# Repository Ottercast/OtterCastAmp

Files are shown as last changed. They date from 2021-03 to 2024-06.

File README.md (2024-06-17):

# OtterCastAmp

OtterCastAmp is an open-source Sonos Amp replacement, based on a Sochip S3 SoC and pulseaudio sink/source.

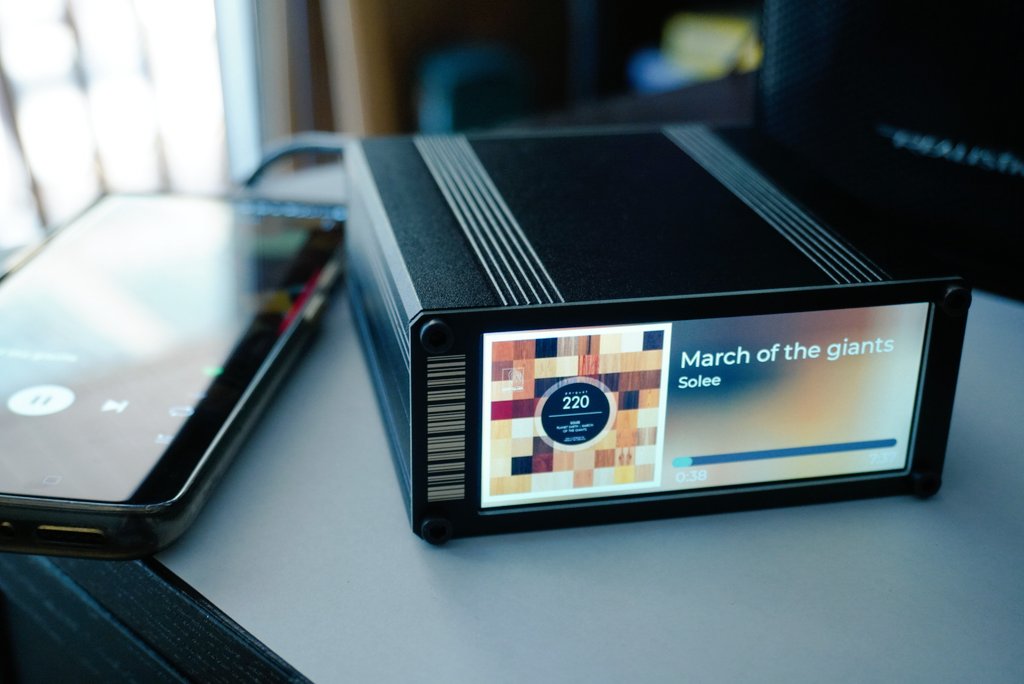
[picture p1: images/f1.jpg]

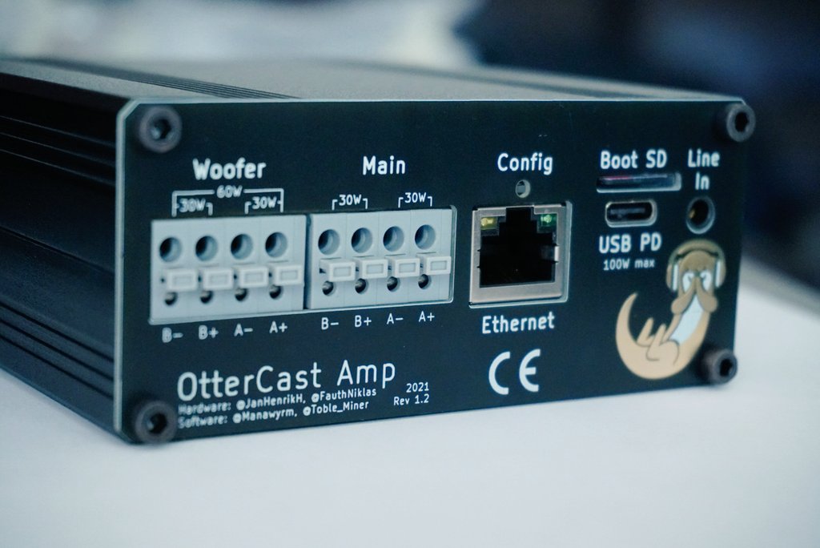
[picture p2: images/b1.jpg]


## How do I get one?

We are currently planning a small batch production run, stay tuned.
[editors notes: It is 2024 now and noone really expected how bad covid would affect the supply chain. While all parts are available again, we are only slowly getting interested in this project again]

You don't want to wait? You can of course run a small batch on your own! Please have a look into the [gerber folder](/gerber_v1.2), a batch size of just 5 (and up to 30) boards is supported by JLC.

## Installation & Configuration

After [downloading and flashing](https://cast.otter.jetzt/docs/firmware/#download-ready-made-images) the image, OtterCastAmp can either be configured via the `config.ini` file or via the web-interface.

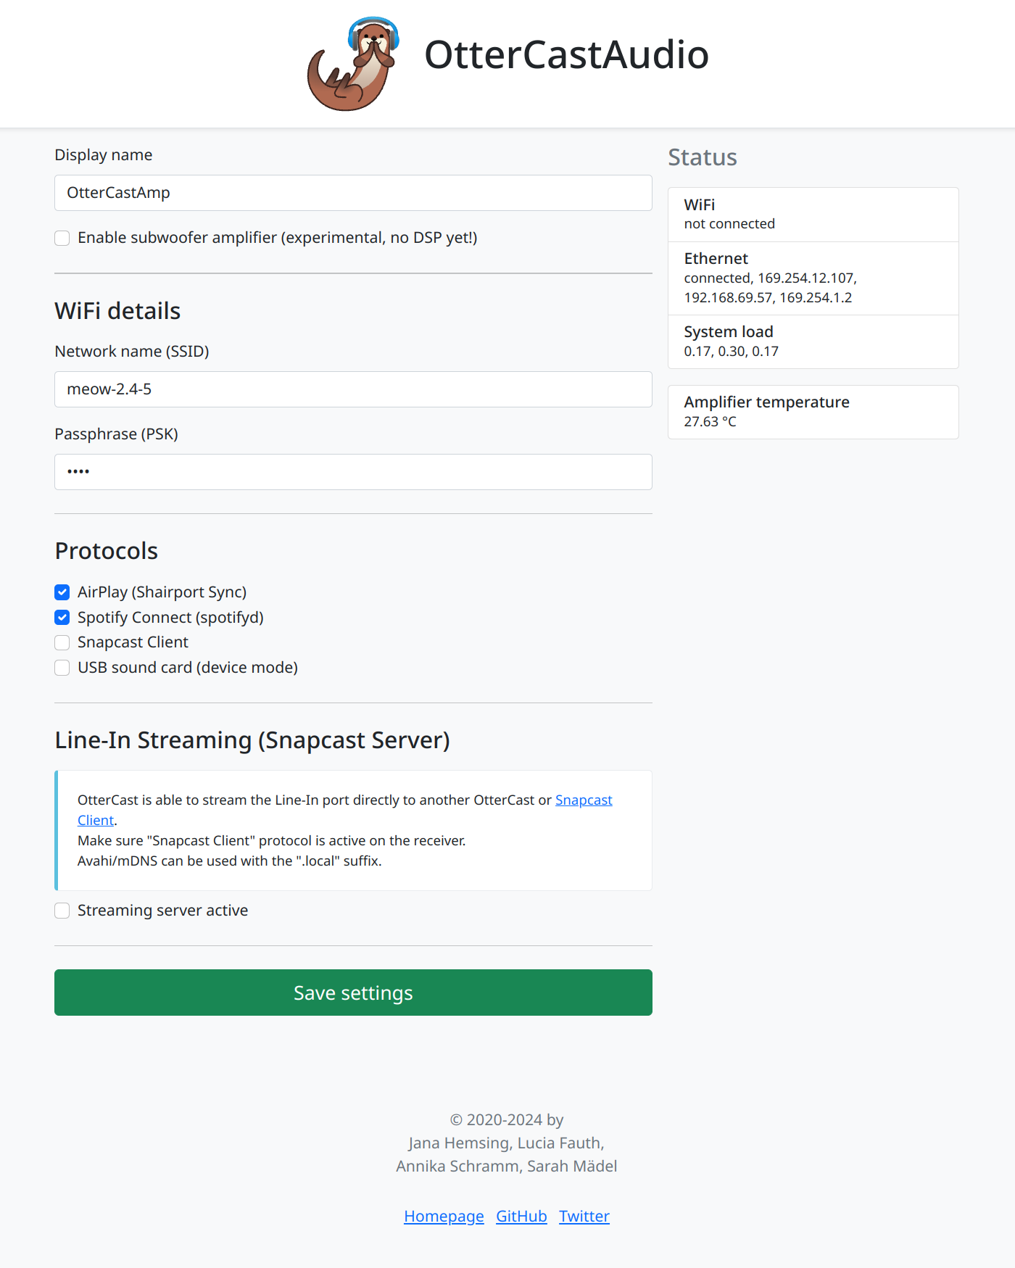
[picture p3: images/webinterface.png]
Screenshot of the webinterface provided by the OtterCastAmp


Check out our [Documentation](https://cast.otter.jetzt/docs/) for more information!

## Schematics?

[Schematics!](/schematic_V1.2/OtterCastAmp.pdf)

## Team

 - [@lucysrausch](https://bsky.app/profile/lucysrausch.bsky.social) Hardware - OtterCastAmp
 - [@_Jana_Marie](https://twitter.com/_Jana_Marie) Hardware - OtterCastAudio
 - [@Toble_Miner](https://twitter.com/Toble_Miner) Software - Embedded Linux
 - [@Manawyrm](https://twitter.com/Manawyrm) Software - Frontend & OTA

## Do you plan a PoE version?

Maybe.
(25W of power is not enough and >50W isn't popular)

## Status

HW v1.0 is ordered and we already found bugs fixed in v1.2 (not ordered yet)
Tested & working:

 - [x] Audio Speaker Out
 - [x] Audio Line In
 - [ ] Bluetooth Audio In
 - [x] USB PD
 - [x] WiFi
 - [x] Ethernet
 - [x] Display
 - [x] Uart

 - [x] Webinterface (config)
 - [x] Shairport-sync
 - [x] Pulseaudio sink
 - [x] Pulseaudio source
 - [x] snapcast

## License

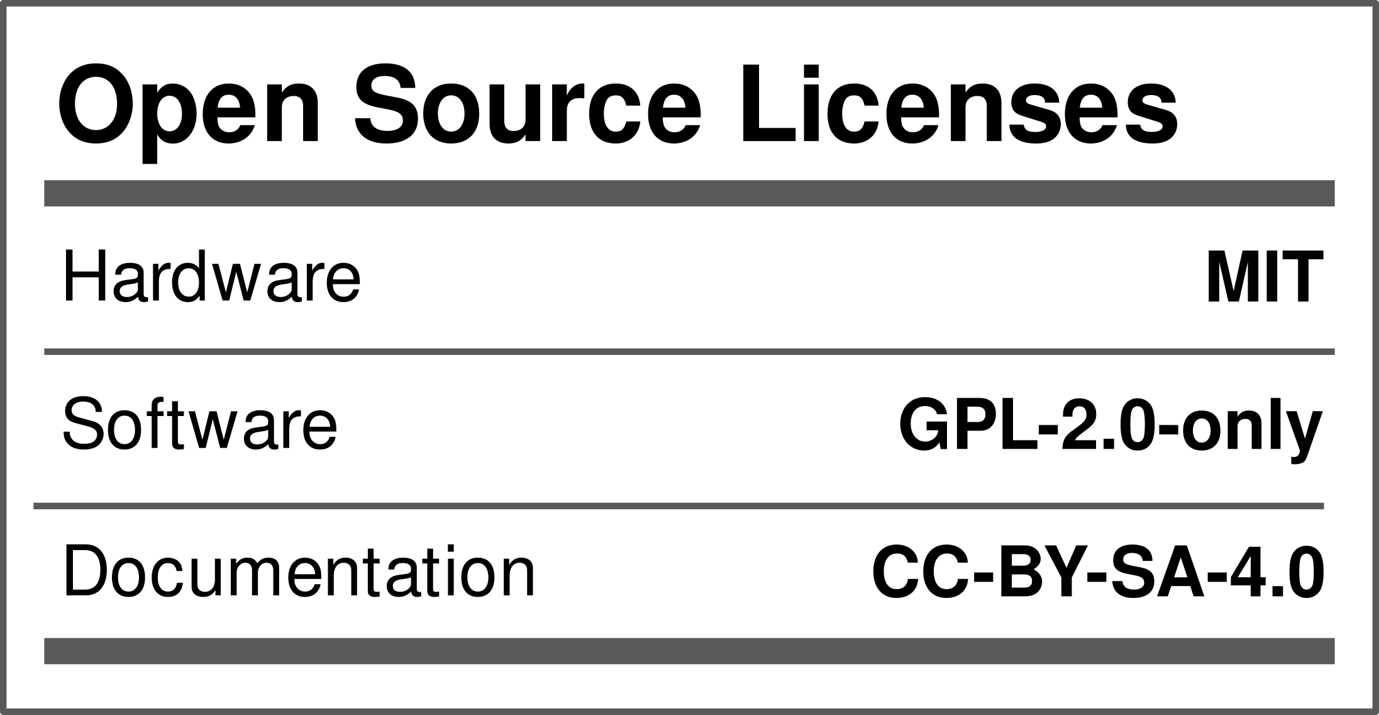
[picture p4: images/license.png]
MIT Licensed HW


Note: The following files or directories are excluded from the License and are otherwise licensed

 - 3D/
 - datasheets/

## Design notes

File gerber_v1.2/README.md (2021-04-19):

## Build Instructions

### Step 1: Get preassembled PCBs from JLCPCB
There are ready-to-order gerber files in this repo. Make sure to choose these settings when ordering the PCBs.

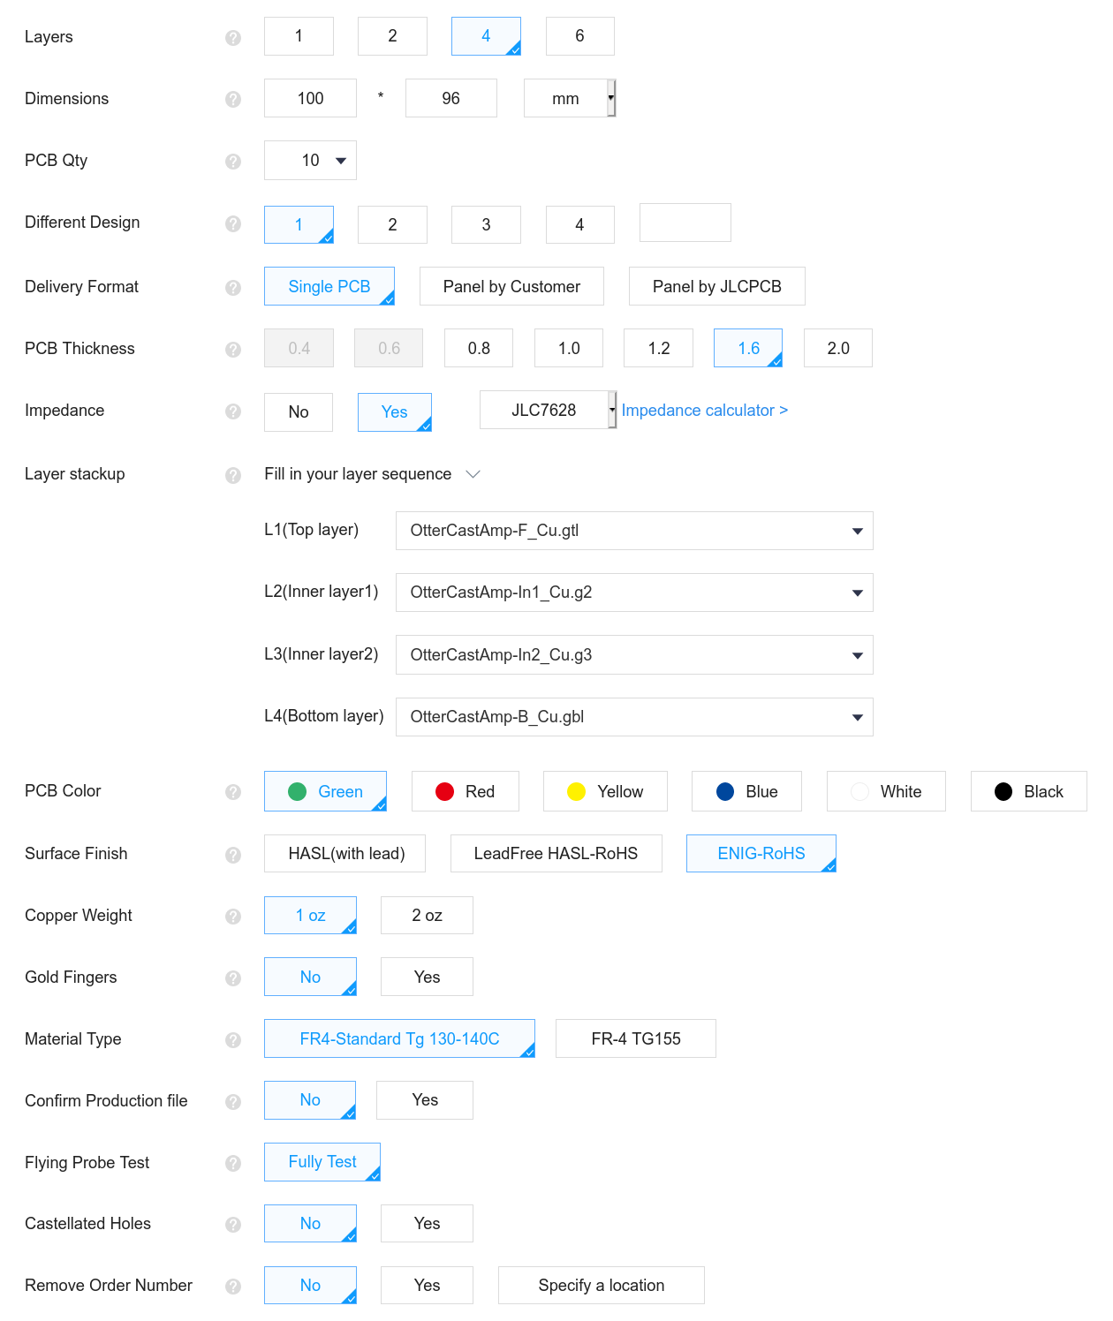
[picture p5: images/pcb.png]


For the front and back PCB, use these settings:

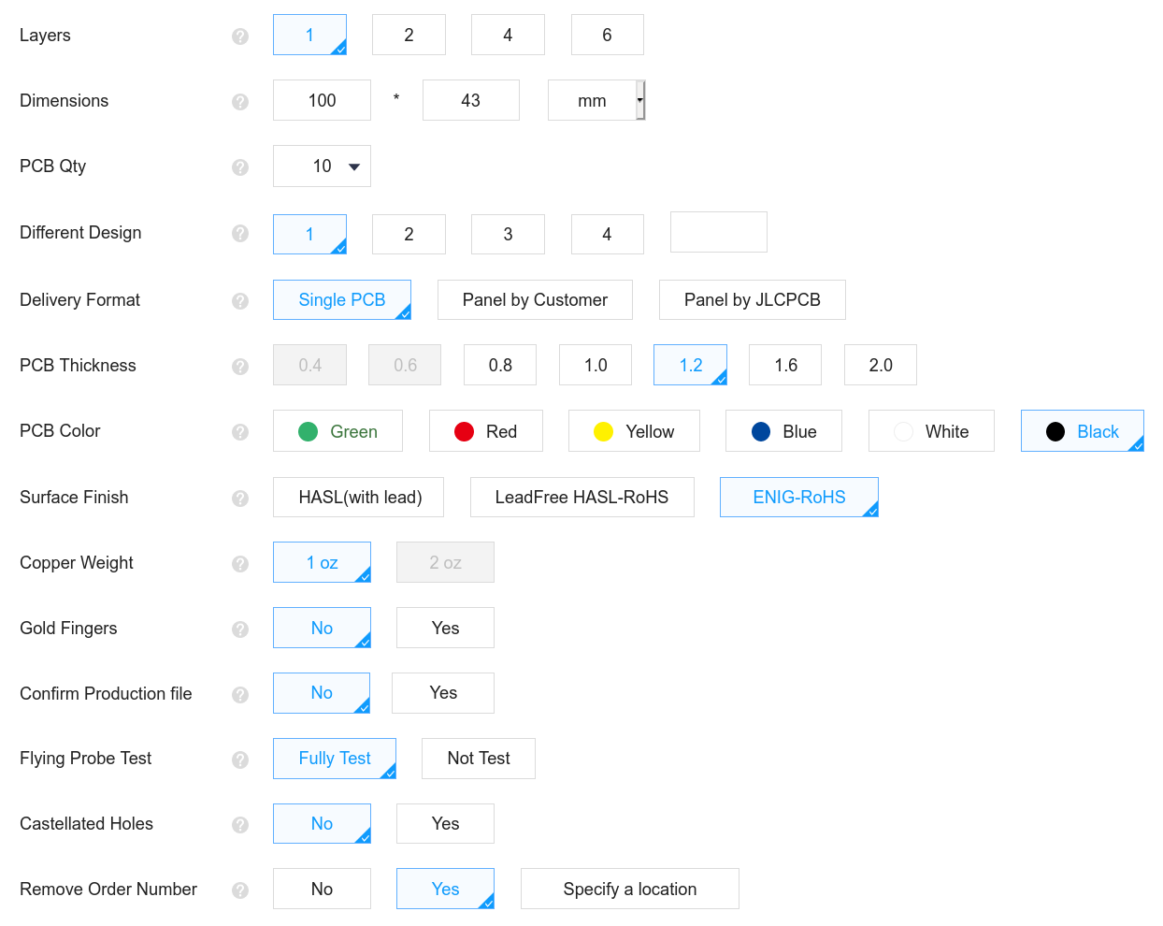
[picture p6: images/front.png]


You can use JLCPCB's assembly service to get most parts assembled. With the current supplychain situation, not all parts are available. Some parts can not be assembled by JLCPCB and have to be soldered on manually.

The price for 10pcs assembled PCBs is $30 in PCBs and $200 in parts.

### Step 2: Buy additional parts
You will need:
LCD KD35WVFPD107  
https://aliexpress.com/item/4001112368958.html

Allwinner S3  
https://aliexpress.com/item/4001284135834.html

AP6255  
https://aliexpress.com/item/4000302317437.html

Case (comes in black if you contact the seller)  
https://aliexpress.com/item/32591351153.html

A bunch of LCSC parts  
C475204, C424654, C12074, C91145, C388883, C381134, C454912

Mouser / DigiKey  
STUSB4500QTR, TAS5825M

Misc  
12x20x50mm Aluminium Block
M3x8 Screws

### Step 3: Assemble OtterCastAmp

Video tutorial follows soon...

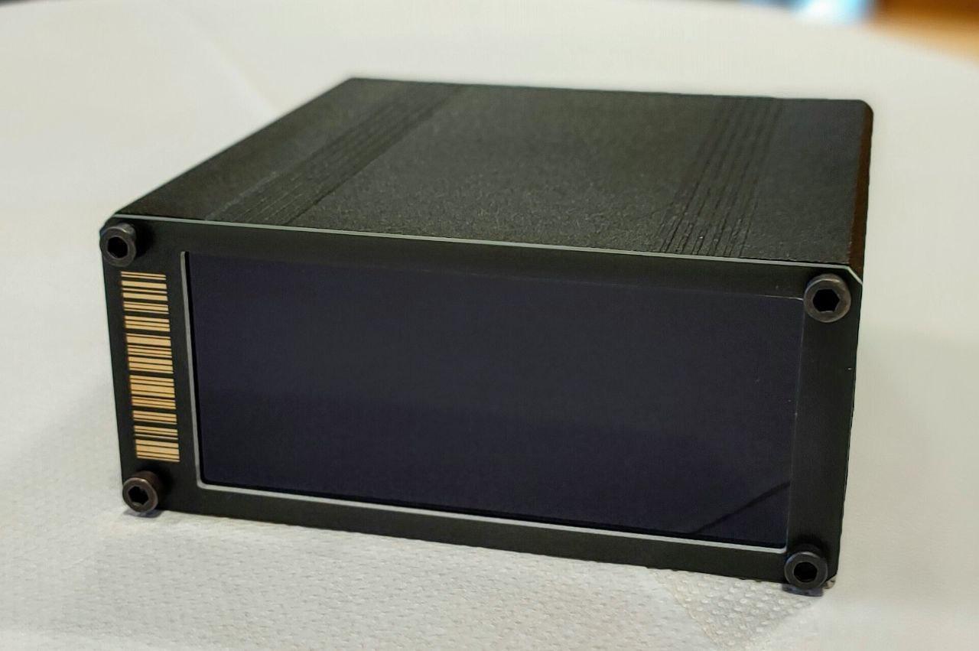
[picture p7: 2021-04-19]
images/f.jpg

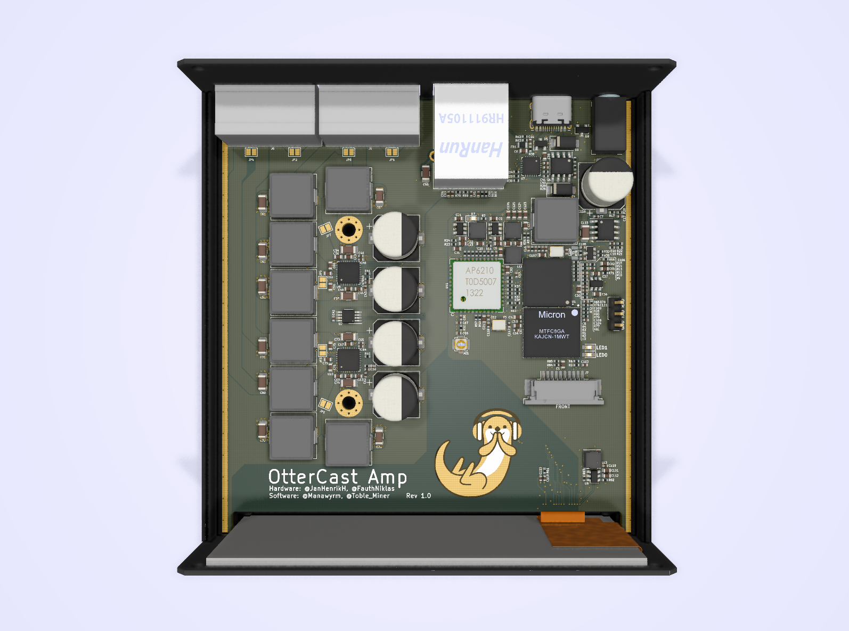
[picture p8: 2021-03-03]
images/render.png

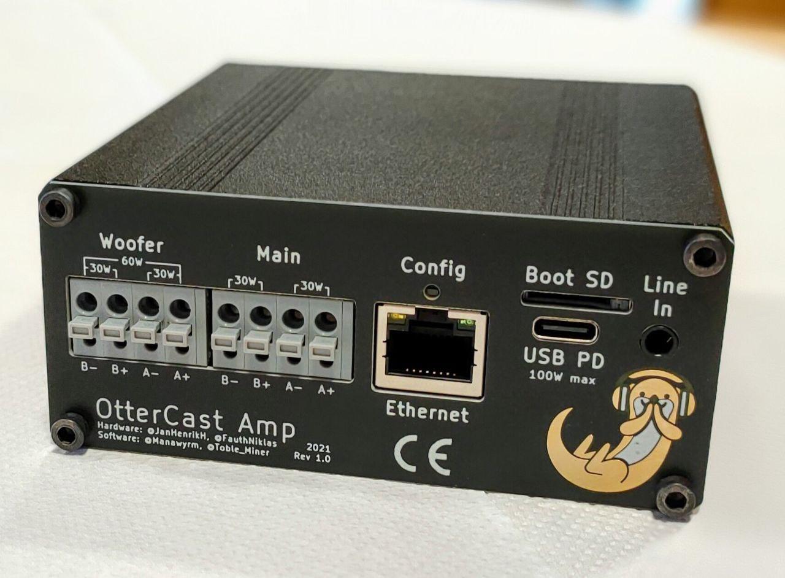
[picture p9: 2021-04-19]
images/b.jpg

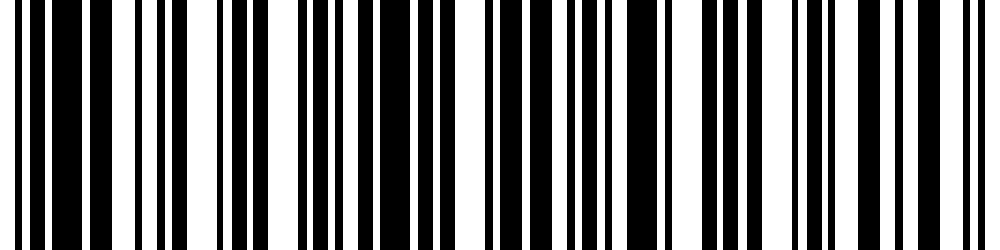
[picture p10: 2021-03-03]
front/barcode/barcode.png

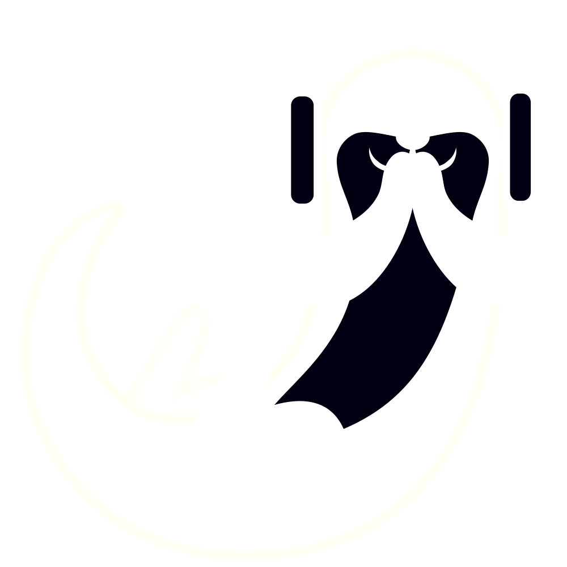
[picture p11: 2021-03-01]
graphics/ottercast/silk.png

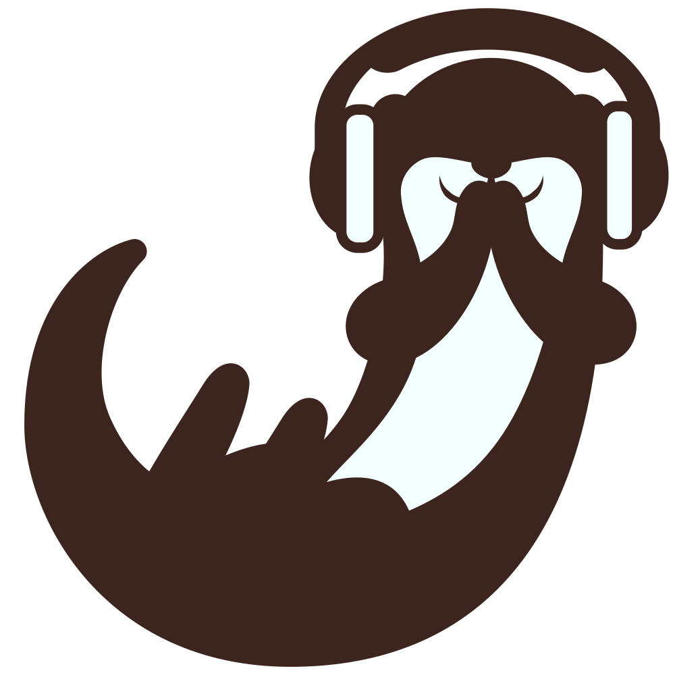
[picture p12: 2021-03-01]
graphics/ottercast/mask.png

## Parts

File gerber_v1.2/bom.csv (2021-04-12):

Comment | Designator | Footprint | LCSC Part # | LCSC Part Type
2.2k | R89,R85,R84,R36,R8,R7,R63,R62,R28,R79,R77,R6,R5 | R_0402 | C25879
TestPoint | VSYNC,HSYNC,DCLK,ENAB,B1,CS,SCLK,COPI | TestPoint_Pad_1.0x1.0mm
0R | R88,R87,R86,R60,R41,R40,R32,R31 | R_0402 | C17168
C475204 | J6,J5 | C475204
UART1 | J4 | PinHeader_1x03_P2.54mm_Vertical
LOGO | G*** | ottercast_mask
LOGO | G*** | ottercast_enig
LOGO | G*** | ottercast_silk
FH26W-33S-0.3SHW | J10 | Molex_502250-3391_2Rows-33Pins-1MP_P0.60mm_Horizontal
EMMC04G-S100-B08U | IC1 | MICRON_EMMC_153 | C391255
AllWinner-S3(FBGA-234) | U1 | FBGA-234(Pitch-0.65mm_Pad-0.3mm_11x11x1.08mm)
GNDA | JP11 | SolderJumper-2_P1.3mm_Bridged_Pad1.0x1.5mm
AP3019A | U8 | SOT-23-6 | C44956
CONFIG | SW1 | SW_SPST_EVQP7C
10R | R83 | R_0402 | C25077
10k | R82,R44,R43,R42,R39,R38,R37,R65 | R_0402 | C25744
47k | R61,R20,R18,R4,R2,R1,R58,R57,R52,R51,R50,R49,R48,R47,R15,R14,R13,R11,R10,R9 | R_0402 | C25792
22u | L12 | Inductor_4040 | C135264
AFA07-S10FCC-00 | J7 | TE_1-84952-0_1x10-1MP_P1.0mm_Horizontal
ESD5302F | D8,D6,D5 | SOT-23 | C313022
470n 25V | C112,C79,C75,C71,C69,C60,C56,C52,C50 | C_0603 | C170149
100n | C110,C120,C119,C42,C62,C43,C39,C11,C5,C3,C111,C108,C104,C103,C102,C100,C98,C94,C93,C91,C90,C89,C84,C82,C29,C19,C17,C16 | C_0402 | C1525
HR911105A | J1 | RJ45_Hanrun_HR911105A
Micro_SD_Card | J2 | SUNTECH_ST-TF-003A
LED | D7,D1 | LED_0603 | C72043
LED | D2 | LED_0603 | C72038
10u | C127,C126,C125,C124,C123,C63,C44,C37,C36,C23,C22,C21,C13,C12,C10,C9,C8,C4,C107,C101,C97,C88,C83,C81,C35,C31,C20,C6,C1 | C_0603 | C19702
PBTL | JP8,JP7,JP6,JP5,JP4,JP3,JP2,JP1 | SolderJumper-2_P1.3mm_Open_Pad1.0x1.5mm
26MHz | Y3 | Oscillator_3225 | C70586
22pF | C118,C117 | C_0402 | C1555
TAS5825MRHB | U10,U9 | Texas_S-PVQFN-N32_EP3.45x3.45mm | C471049
10u | L11,L10,L9,L8,L7,L6,L5,L4 | L_10.4x10.4_H4.8 | C182194
15uH | L1 | L_10.4x10.4_H4.8 | C182194
STUSB4500 | U7 | QFN-24-1EP_4x4mm_P0.5mm_EP2.7x2.7mm | C2678061
470u 35V | C116,C78,C77,C59,C58 | CP_Elec_10x10.5 | C3350
22u 50V | C115,C74,C73,C55,C54 | C_1206_3216Metric | C12891
100n 50V | C68,C67,C49,C48 | C_0603 | C14663
MP2303 | U4 | SOIC-8-1EP_3.9x4.9mm_P1.27mm_EP2.29x3mm | C18876
LM75B | U2 | VSSOP-8_3.0x3.0mm_P0.65mm | C33099
100k | R78,R35,R34,R33,R26,R24,R23,R17,R16 | R_0402 | C25741
1k | R46,R30 | R_0402 | C11702
DNP | R45,R71,R68 | R_0402
22k | R29 | R_0402 | C25768
100R | R27,R56,R55,R54 | R_0402 | C25076
5.6k | R22,R75 | R_0402 | C25908
15k | R21 | R_0402 | C25756
68k | R19 | R_0402 | C36871
22 | R3,R64,R59,R53,R25,R12 | R_0402 | C25092
2.2uH | L13 | Inductor_4040 | C408335
2u2 | L3,L2 | Inductor_4040 | C408335
3.2mm | H2,H1 | MountingHole_3.2mm_M3_Pad_Via
SMAJ22A | D4,D3 | D_SMA | C148220
1n 2kV | C96 | C_1206_3216Metric | C35216
1u 25V | C95,C92,C38 | C_0603 | C15849
680n 50V | C80,C76,C72,C70,C61,C57,C53,C51 | C_1206_3216Metric | C307578
1u | C66,C65,C64,C47,C46,C45,C41,C40 | C_0402 | C52923
10n | C7 | C_0402 | C15195
DNP | C2,C87,C86 | C_0402
u.FL | AE1 | U.FL_Molex_MCRF_73412-0110_Vertical | C88374
24MHz | Y2 | Oscillator_3225 | C164058
32.768kHz | Y1 | Crystal_SMD_3215-2Pin_3.2x1.5mm | C32346
AP6236 | U11 | LGA_44_12x12mm_0.9mm
MIC5501-3.0YM5 | U6 | SOT-23-5 | C57079
SY8089AAAC | U5,U3 | SOT-23-5 | C78988
240 | R81,R80 | R_0402 | C25094
10M | R76 | R_0402 | C26082
6k04 | R74 | R_0402 | C25913
200k | R73,R72 | R_0402 | C25764
51 | R70,R69,R67,R66 | R_0402 | C25125
DMP4015SS | Q1 | SOIC-8_150mil | C508210
PJ-3270 | J9 | PJ-3270
USB | J3 | USB-C 16Pin | C165948
FERRET | FB1 | R_0805 | C1017
18p | C113,C109,C106,C105,C85 | C_0402 | C1549
3.3n | C18 | C_0402 | C26404

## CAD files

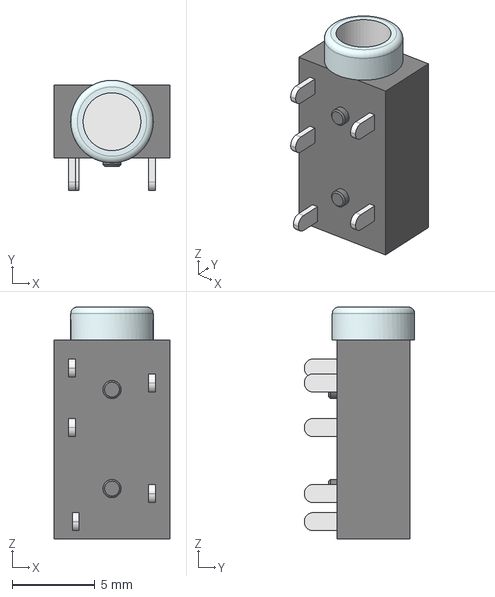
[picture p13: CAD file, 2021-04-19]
3D/PJ-3720.step
7.00 x 6.69 x 14.1 mm

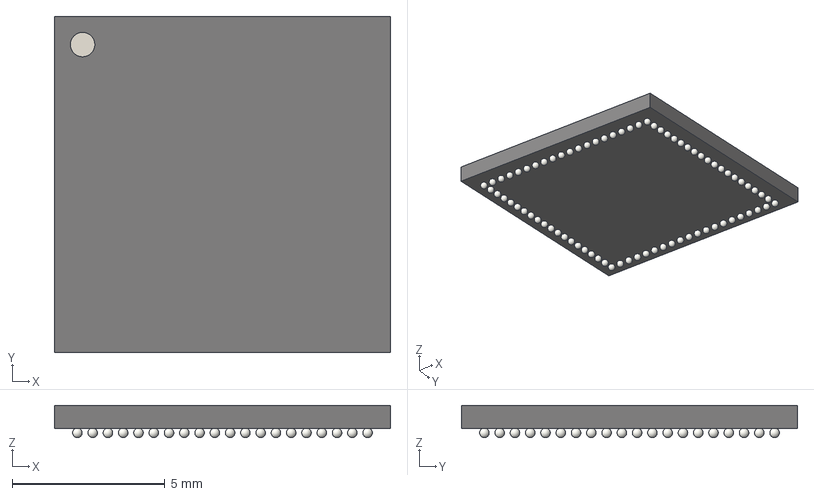
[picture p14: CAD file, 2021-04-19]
3D/BGA-256_11.0x11.0mm_Layout20x20_P0.5mm_Ball0.3mm_Pad0.25mm_NSMD.step
11.0 x 11.0 x 1.06 mm

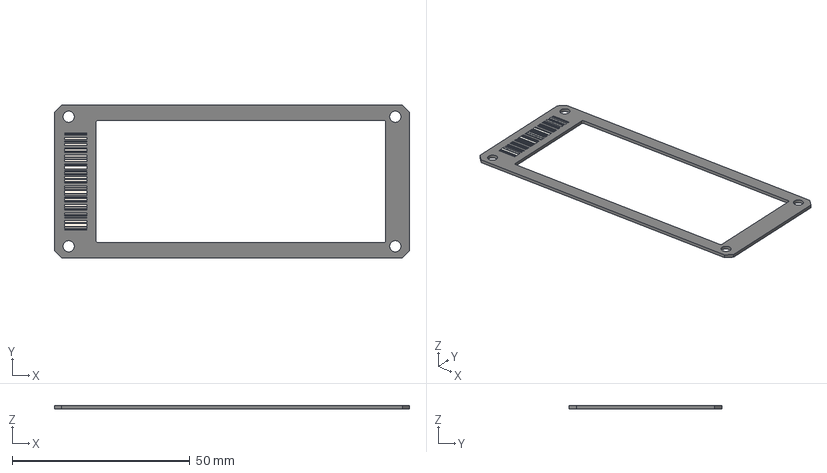
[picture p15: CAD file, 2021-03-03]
3D/front.step
100.0 x 43.0 x 1.07 mm
Local_CS
PCB_Sketch
topSilks
Step_Models

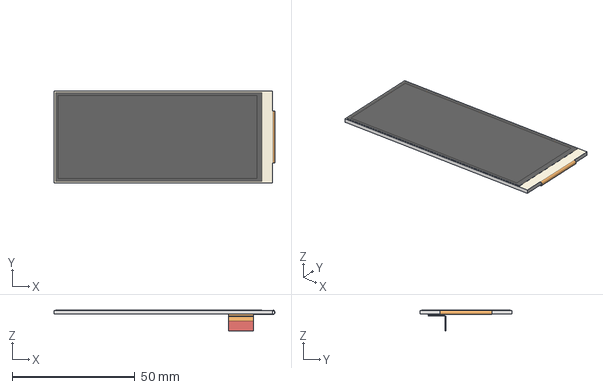
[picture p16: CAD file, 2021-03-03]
3D/lcd.stp
90.0 x 37.3 x 8.54 mm

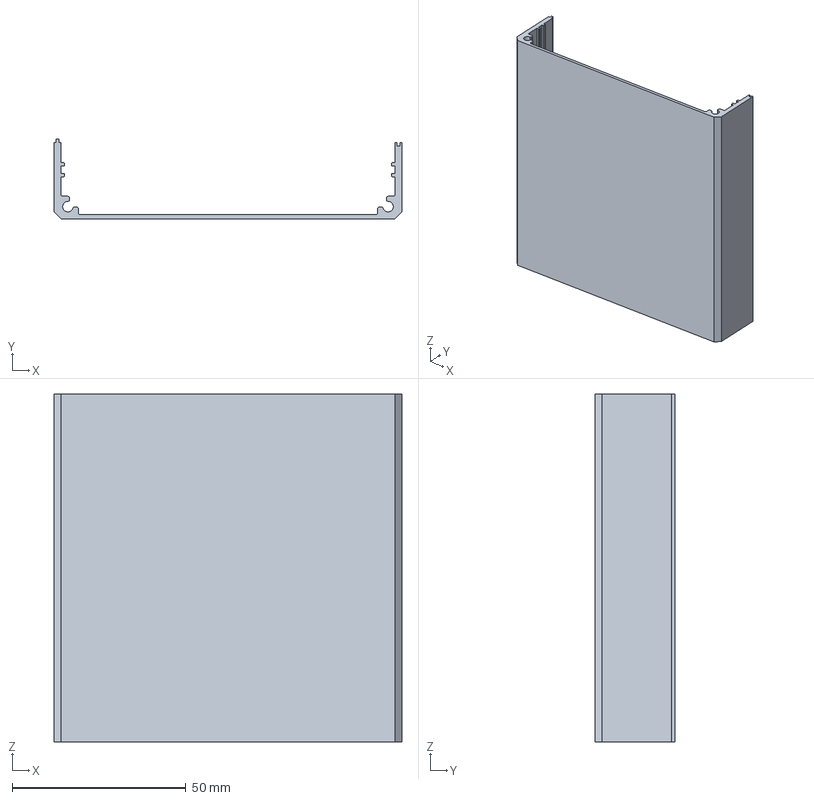
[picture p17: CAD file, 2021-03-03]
3D/ottercast_case.stp
100.0 x 22.9 x 100.0 mm

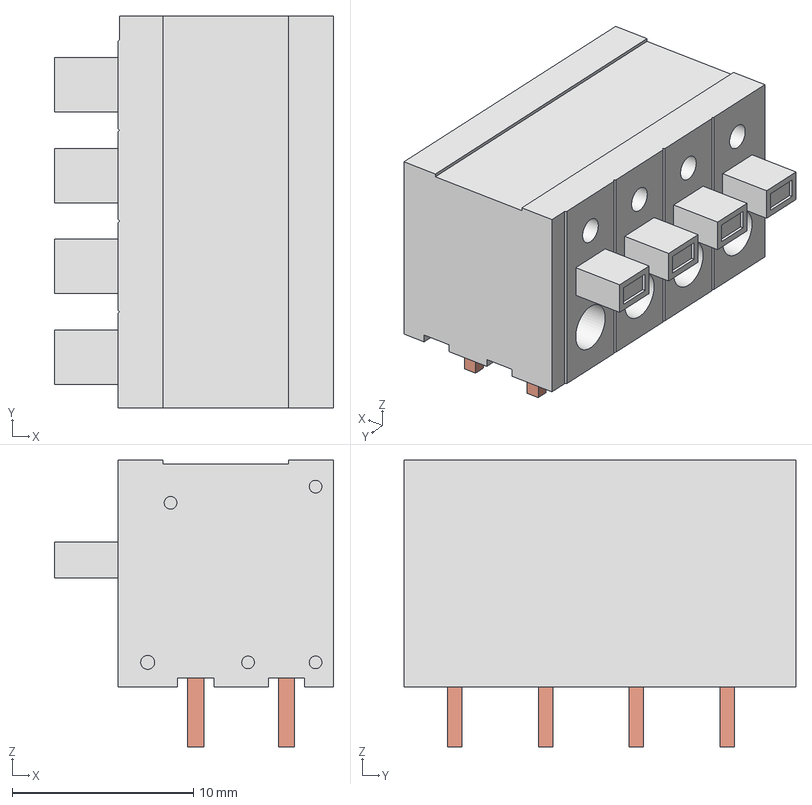
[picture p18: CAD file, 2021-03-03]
3D/KF211R.stp
15.4 x 21.6 x 15.8 mm

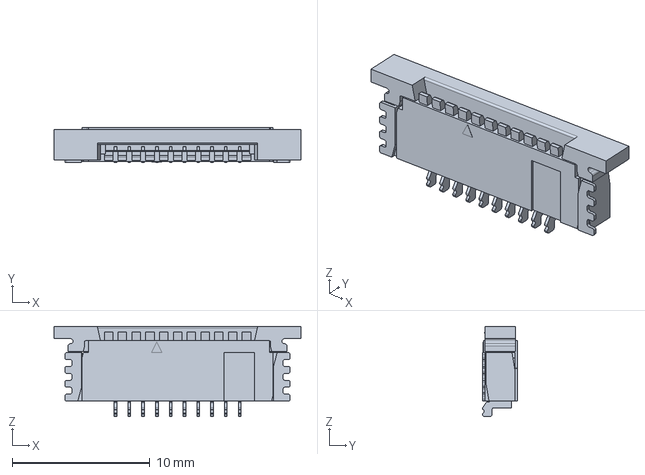
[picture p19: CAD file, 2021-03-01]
3D/c-1-84952-0-a-3d.stp
17.9 x 2.56 x 6.54 mm

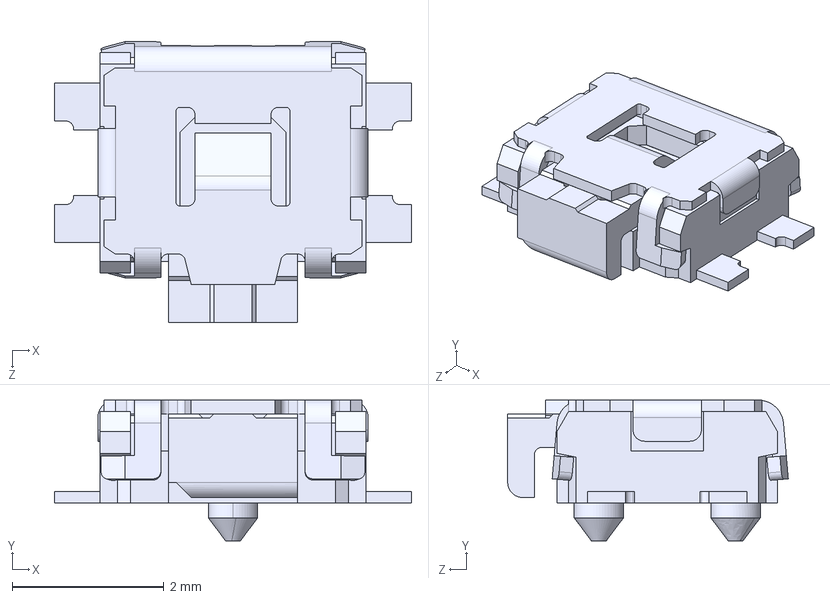
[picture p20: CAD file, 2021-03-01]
3D/User Library-EVQP7-LC-01P-1.STEP
4.70 x 1.85 x 3.69 mm

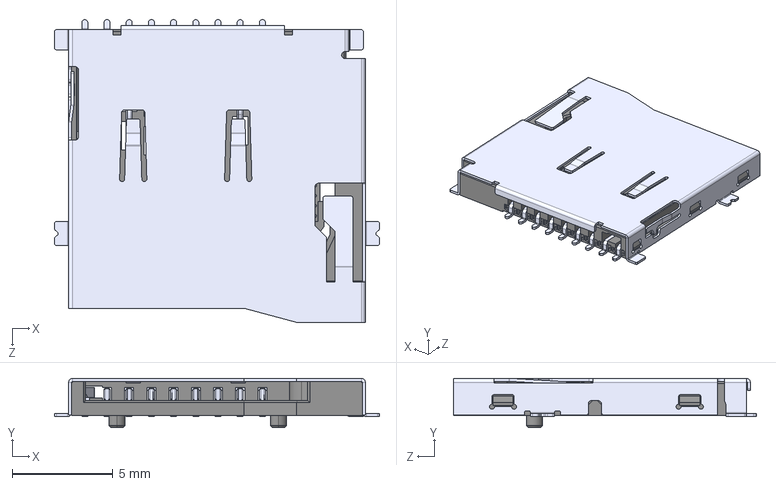
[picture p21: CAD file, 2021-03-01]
3D/ST-TF-003A--3DModel-STEP-56544.STEP
16.1 x 2.45 x 15.0 mm

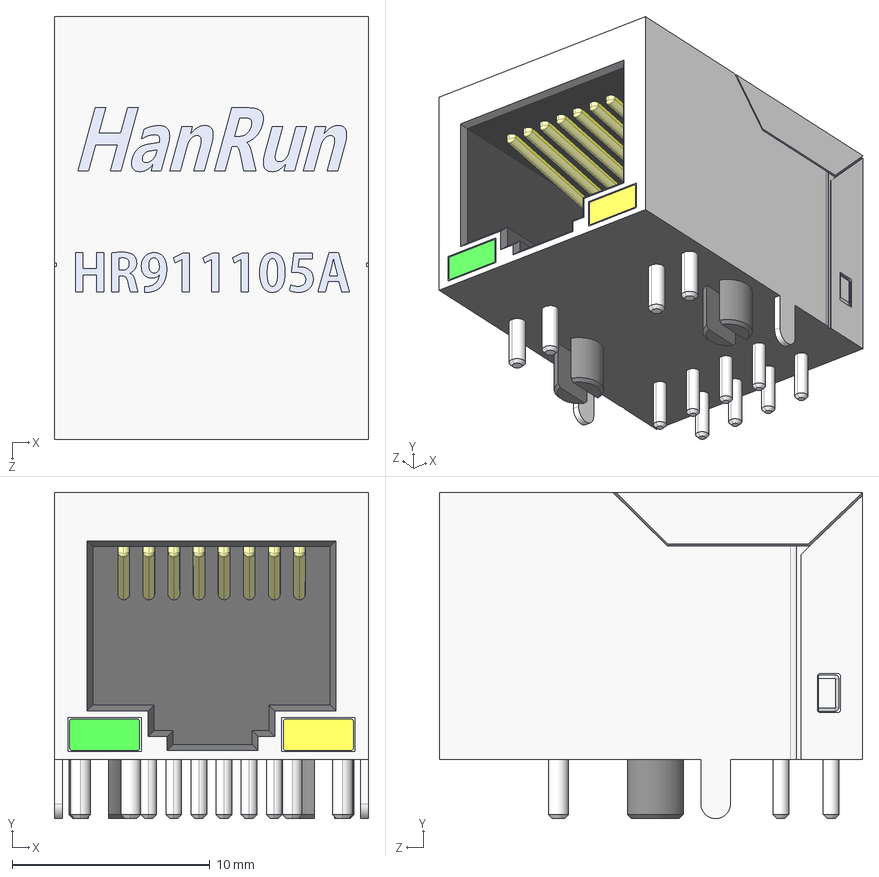
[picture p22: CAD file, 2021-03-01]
3D/User Library-HR911105A.STEP
15.9 x 16.5 x 21.4 mm

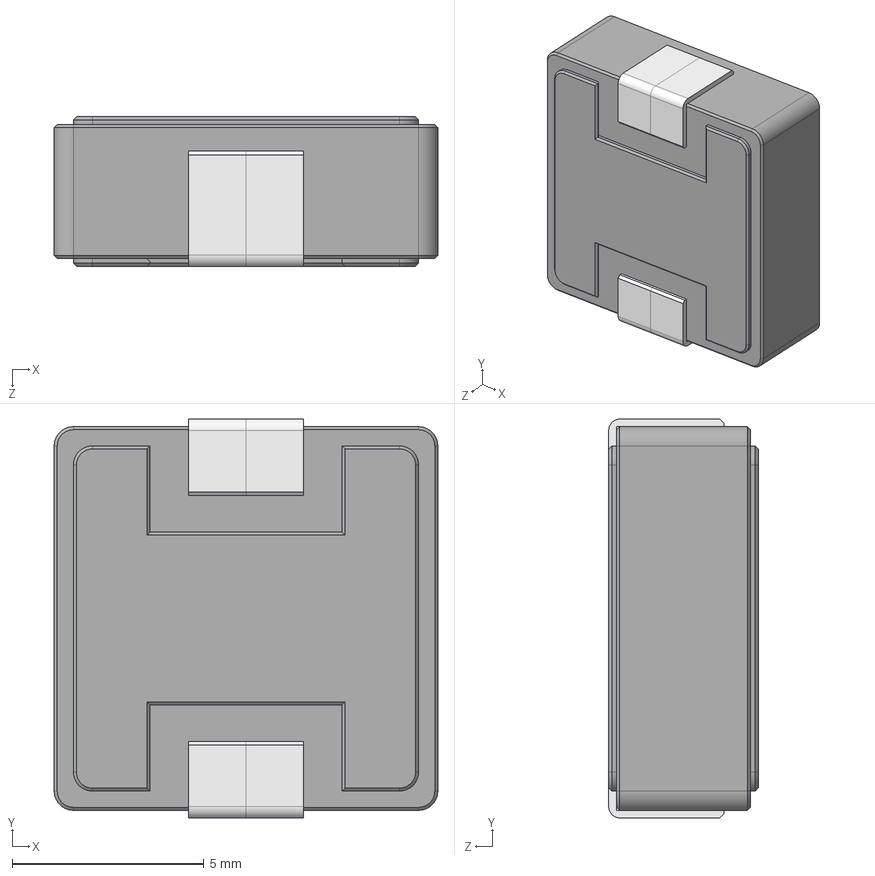
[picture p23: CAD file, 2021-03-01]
3D/User Library-SMPI1004HW.step
10.0 x 10.4 x 3.90 mm

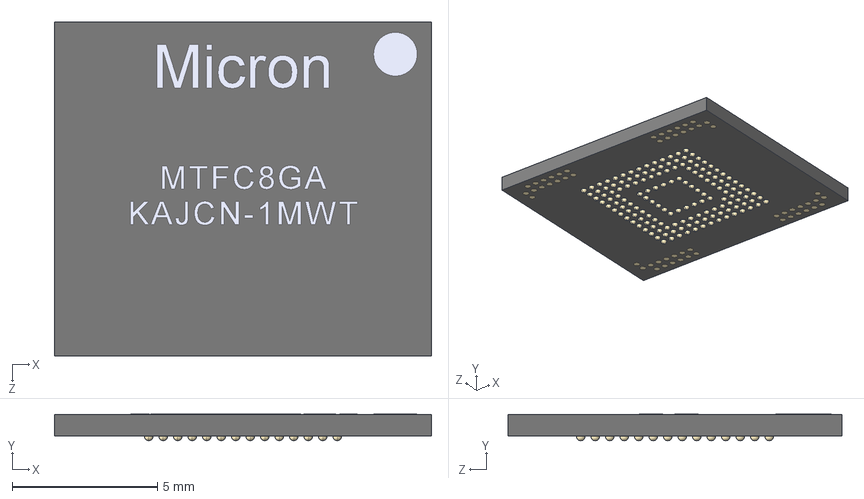
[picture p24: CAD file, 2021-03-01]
3D/MTFC8GAKAJCN-1MWT.STEP
13.0 x 0.914 x 11.5 mm

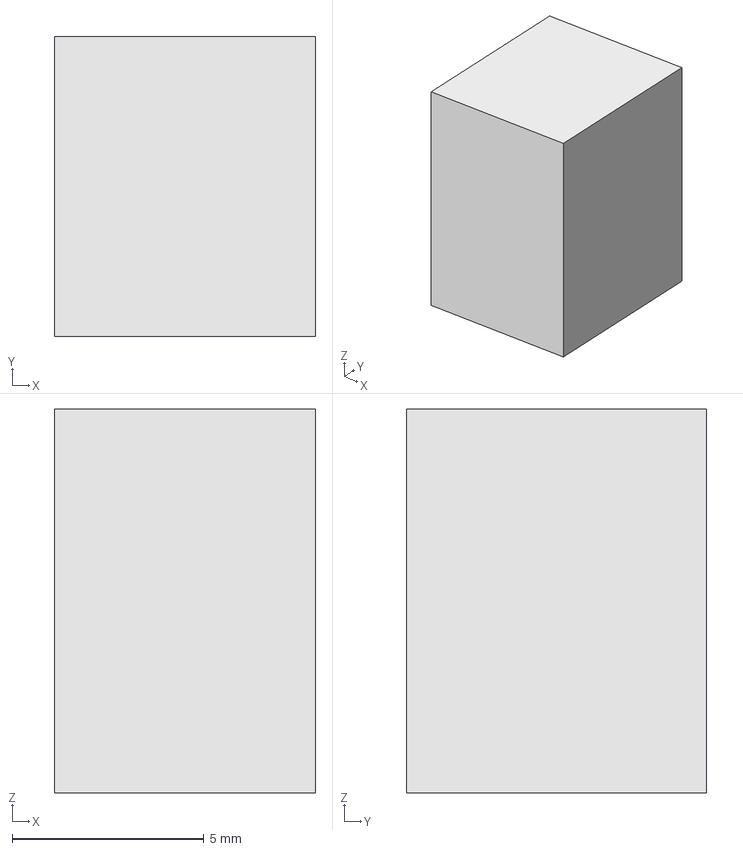
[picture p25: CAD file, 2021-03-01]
3D/inductor_US.step
6.80 x 7.80 x 10.0 mm

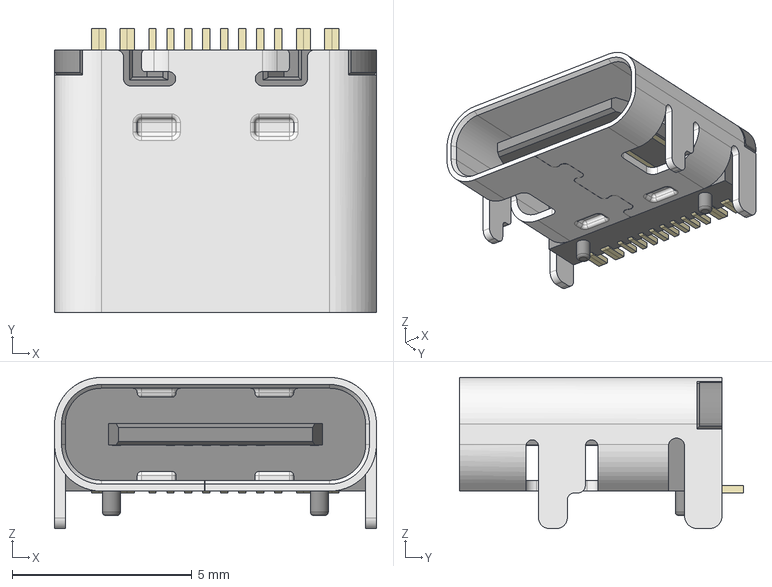
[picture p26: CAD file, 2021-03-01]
3D/HRO_TYPE-C-31-M-12.step
8.95 x 7.90 x 4.20 mm

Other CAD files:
3D/u.Fl Antenna Connector - 523-A-1JB.STEP
front/gerber_front/front-F_SilkS.dxf

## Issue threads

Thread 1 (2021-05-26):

USB drive support

erdnaxe, 2021-05-26:
From my understanding of the OtterCastAmp v1.2 schematic, the only way to play music from an external USB drive is to use an USB-C hub with power pass-through.

Should I expect most of the USB-C hubs to work nicely with OtterCastAmp, or should I rather try to remix the design with either:
- Have two USB ports, one for power, one for data ;
- Add an internal USB 2.0 hub for another USB port?

What is your opinion on simplifying the use of an USB drive in future versions?

Thank you for all this amazing work!

Manawyrm, 2021-05-26:
Hi!

Currently USB host mode doesn't work due to a still unknown bug.
It should work and it's most likely a software issue, but we're not 100% sure.

USB device mode (as a sound card) does work, so the USB itself is fine.

Just general purpose USB-C hubs for notebooks and smartphones should work fine.

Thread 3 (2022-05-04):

v1.2 status

timothy-godfrey, 2022-05-04:
Hello! Just checking in to see how the Ottercast amp is coming along. Did you get a run of v1.2 boards fabricated? Did you get a chance to test them? Are they in regular use?

I hope the project is coming along, and that you're all doing well. Best regards!

SebastianTs, 2022-05-09:
Hi I just stumbled across this project and I am very impressed. Unfortunately, the necessary SoC ALLWINNER S3 BGA 2020 seems to be currently not available. Is that perhaps the reason why the promised assembly video is missing and generally seems to be relatively little going on here?

Jana-Marie, 2022-05-10:
Hey! yea, due to supply chains issues both, the OtterCastAudioV2 and Amp are currently a bit on pause. Sorry for that!

salembegic, 2024-11-03:
Hi, just wanted to say that this seems like a really cool project, and I honestly hope you will continue the development at some point. Best regards😁😁

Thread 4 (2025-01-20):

Help with a personal build

salembegic, 2025-01-20:
Hi, I recently got all the components and built the Ottercastamp with the help of a few friends. In the beginning everything seemed to work fine, and we managed to enter the SSID and password through configuration port, but then we noticed that the amp wasn't connecting to the wifi we set. Since then we tried multiple things (reflowing, changing the chips...) but we still can't get it to work.

If you have any clues a to what I could try, i would be very grateful. This is the output I get when connecting to UART:

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

Manawyrm, 2025-01-20:
(currently traveling and a bit short on time, ping me again later for more detailed debugging)

What happens via Ethernet? Have you tried to put an SSH key onto the SD card and logging into the amp?

Logging in via serial (username root), can you run „ip a“? What happens there?

Is your WiFi set to WPA3? Protected Management Frames might be a problem.
Try downgrading your WiFi to WPA2(-PSK).

salembegic, 2025-01-22:
Hi, thank you so much for helping out 😊

When I connect to it over ethernet everything seems to be working fine. I tried going to the IP address and I got the configuration site:

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

SSH also works as expected. I tried running the ip a command, and this is the output I got:

`ip a␍␊
1: lo:  mtu 65536 qdisc noqueue state UNKNOWN group default qlen 1000␍␊
    link/loopback 00:00:00:00:00:00 brd 00:00:00:00:00:00␍␊
    inet 127.0.0.1/8 scope host lo␍␊
       valid_lft forever preferred_lft forever␍␊
    inet6 ::1/128 scope host ␍␊
       valid_lft forever preferred_lft forever␍␊
2: eth0:  mtu 1500 qdisc mq state DOWN group default qlen 1000␍␊
    link/ether 02:01:e4:83:88:63 brd ff:ff:ff:ff:ff:ff␍␊
3: sit0@NONE:  mtu 1480 qdisc noop state DOWN group default qlen 1000␍␊
    link/sit 0.0.0.0 brd 0.0.0.0␍␊
	`
My WiFi is currently set to allow both WPA2 and WPA3, and the few Pi's/ESPs I have lying around seem to be working fine. My best guess is that it's a hardware issue. I will try to check the WiFi chip over the next few days to see if there is any activity. I already tried replacing it since I had spares, but it might be a problem with crystal or other passive components.

Do you maybe know if there is any way to see devices conected to the main chip? I would like to know if the S3 can at least communicate with amplifier chips, an if not I can try reflowing it or even reballing and soldering it again. I also talked with a friend and I might be able to get it under x-ray to see if there are any shorts/cold joints under it.

Manawyrm, 2025-01-22:
> this is the output I got

Yeah, OK, that's pretty clear, then.
You don't have any WiFi interface.

> Do you maybe know if there is any way to see devices conected to the main chip?

There is no "standardised interface" or discovery mechanism for this.
You can just use the (working) Ethernet interface to play audio through the device, though?
If it works, it works? 😄

The bootlog you've showed doesn't really look very promising, though.
There's no mention of the SDIO-attached WiFi module (just the bluetooth part of it) and there's no mention of the amplifier chips.

Hmm. You could try to run
```bash
i2cdetect -y 0
i2cdetect -y 1
```
to see if there is anything on the bus. Not sure if the kernel will let you do that, but it's worth a try.

>  I also talked with a friend and I might be able to get it under x-ray to see if there are any shorts/cold joints under it.

Sure! Always a good idea.
Where are you located in the world physically?

> My WiFi is currently set to allow both WPA2 and WPA3, and the few Pi's/ESPs I have lying around seem to be working fine.
Some of the modules (and especially the accompanying firmware) seemed to have problems with WPA3/PMF. If you get WiFi working (see a wifi interface in `ip a`), but can't connect, try to remember this limitation. I think we managed to fix it, but I'm not 100% sure right now.
I do know that the 2 Ottercast Amp's we have here for dev/prod have 2 different WiFi chipsets for historical reasons and they behave slightly differently :D

lucysrausch, 2025-01-23:
Hi, and congrats on assembling & booting a Linux SoC from scratch!

That's honestly pretty impressive and unfortunately a pretty high barrier for entry to this project. A future version of OtterCastAmp will replace the SoC with a SOM to hopefully make DIY builds easier and more successful.

To add to @Manawyrm, I'll say that the WiFI module can be a bit funky and gave us quite some trouble during the development. First, it's hard to find genuine modules, as I remember that parts from AliExpress are often rebranded or outdated HW versions. Once I even received an order of "new" modules that very clearly were desoldered and stripped for parts. So, it might even make sense to swap the module for a different part from another batch.

The other thing I remember doing while also debugging firmware, was checking the 1.2V rail on the WiFi SOM for life, and making sure the crystal is oscillating. Tho if you got bluetooth to initialize, this is most likely working since it's a combined SoC for WiFi and BLE. So most likely you are having issues with the SDIO bus or FW. If you have a decent scope with a 10X probe or a _good_ logic analyzer you can also try probing the SDIO bus on the pullup resistors next to the module.

One thing to note for bringing up the amplifiers: Although they could (and tbh should, can we fix this in software? @Manawyrm) work individually, from experience the ALSA driver only fully initializes if both chips are present on the I2C bus. There is also a temperature sensor you can probe for (both physically and from the kernel) to see if the bus is present at all. If not, it's most likely a soldering issue with the SoC. If you can get an xray, that would help for sure with further debugging.

Good luck!!

Aqe92, 2025-01-25:
Hi. i have made this amp too. After alot of struggling i got this working, but have the same fault with no wifi. I can see the temperature on the website and it is changing so i guess the I2C bus should be working? i have placed an order for new wifi modules.
I have it working on Ethernet and have a question. When i connect to it from spotify (iphone) the amp always go to max volume
which is not that great and i have to turn it down before connecting any speakers, it is the same on both amp outputs.. Have i done something wrong or is it how its ment to be?.

Would be awesome to get this beauty running.

Best Regards Axel.

[Ottercastamp fault code.txt](https://github.com/user-attachments/files/18545021/Ottercastamp.fault.code.txt)

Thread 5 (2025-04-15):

Support with the device tree for dual TAS5805M DAC

anabolyc, 2025-04-15:
Hey folks, I'm building a Raspberry Pi Hat that uses two TAS5805M DACs connected in a 2.1 master/slave configuration. The schematics I'm using are very close to the setup of the OtterCastAmp, with the key difference of using TAS5805M DAC instead of TAS5825M. The I2C addresses are different, but the rest are the same.

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

The problem I'm having is building the right device tree for that Hat for Raspbian. I started with my own tas5805m driver and tried to implement it similar way to the way you guys did in your [dts](https://github.com/Ottercast/buildroot-ottercast-audio/blob/master/buildroot/board/otter/ottercast-S3/dts/sun8i-s3-ottercast-amp.dts) and [driver patch](https://github.com/Ottercast/buildroot-ottercast-audio/blob/master/buildroot/board/otter/ottercast-S3/linux/patches/0018-ASoC-add-support-for-TI-TAS5825M-smart-digit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). Currently I'm trying to use your code with minimal adjustments for Raspberry but failing.

The closest I got is this device tree that spins up the master DAC with TAS5825M driver.
```dts
/dts-v1/;
/plugin/;

/ {
    compatible = "brcm,bcm2835";

    fragment@0 {
        target = <&i2s>;
        __overlay__ {
            status = "okay";
        };
    };

    fragment@1 {
        target = <&i2c1>;
        __overlay__ {
            status = "okay";
            clock-frequency = <400000>;
            #address-cells = <1>;
            #size-cells = <0>;

            tas5825m_master: tas5825m@2e {
                #sound-dai-cells = <0>;
                compatible = "ti,tas5825m";
                reg = <0x2e>;
                pvdd-supply = <&vdd_3v3_reg>;
                pdn-gpios = <&gpio 4 0>;
                ti,dsp-config-name = "2.0_basic";
                sound-name-prefix = "Main";
            };

            tas5825m_slave: tas5825m@2f {
                #sound-dai-cells = <0>;
                compatible = "ti,tas5825m";
                reg = <0x2f>;
                pvdd-supply = <&vdd_3v3_reg>;
                pdn-gpios = <&gpio 5 0>;
                ti,dsp-config-name = "1.0_basic";
                sound-name-prefix = "Woofer";
            };
        };
    };

    fragment@2 {
        target = <&sound>;
        __overlay__ {
            status = "okay";
            compatible = "simple-audio-card";
            label = "Louder-Raspberry-2X";
            simple-audio-card,widgets =
                "Speaker", "Speaker";
            simple-audio-card,routing =
                "Speaker", "Main OUTA",
                "Speaker", "Main OUTB";
                // "Speaker", "Woofer OUTA",
                // "Speaker", "Woofer OUTB";
            simple-audio-card,dai-link {
                format = "i2s";
                bitclock-master = <&dailink_master>;
                frame-master = <&dailink_master>;
                dailink_master: simple-audio-card,cpu {
                    sound-dai = <&i2s>;
                    dai-tdm-slot-num = <2>;
                    dai-tdm-slot-width = <32>;
                };
                codec@0 {
                    sound-dai = <&tas5825m_master>;
                };
                // codec@1 {
                //     sound-dai = <&tas5825m_slave>;
                // };
            };
        };
    };
};

```

But as soon as I comment out `codec@1` section and corresponding `routing` section, it spits an error on initialisation
```
Apr 15 17:51:25 lab-louder-pi-04 kernel:  tas5825m-amplifier-tas5825m-amplifier: substream tas5825m-amplifier-tas5825m-amplifier has no playback, no capture
Apr 15 17:51:25 lab-louder-pi-04 kernel: asoc-simple-card soc:sound: ASoC: can't create pcm tas5825m-amplifier-tas5825m-amplifier :-22
Apr 15 17:51:25 lab-louder-pi-04 kernel: asoc-simple-card: probe of soc:sound failed with error -22
```

I was hoping that you might see what am I doing wrong, or at least confirm that the configuration I found in your repo is something that is actually working for you, do give me confidence that I'm on the right path

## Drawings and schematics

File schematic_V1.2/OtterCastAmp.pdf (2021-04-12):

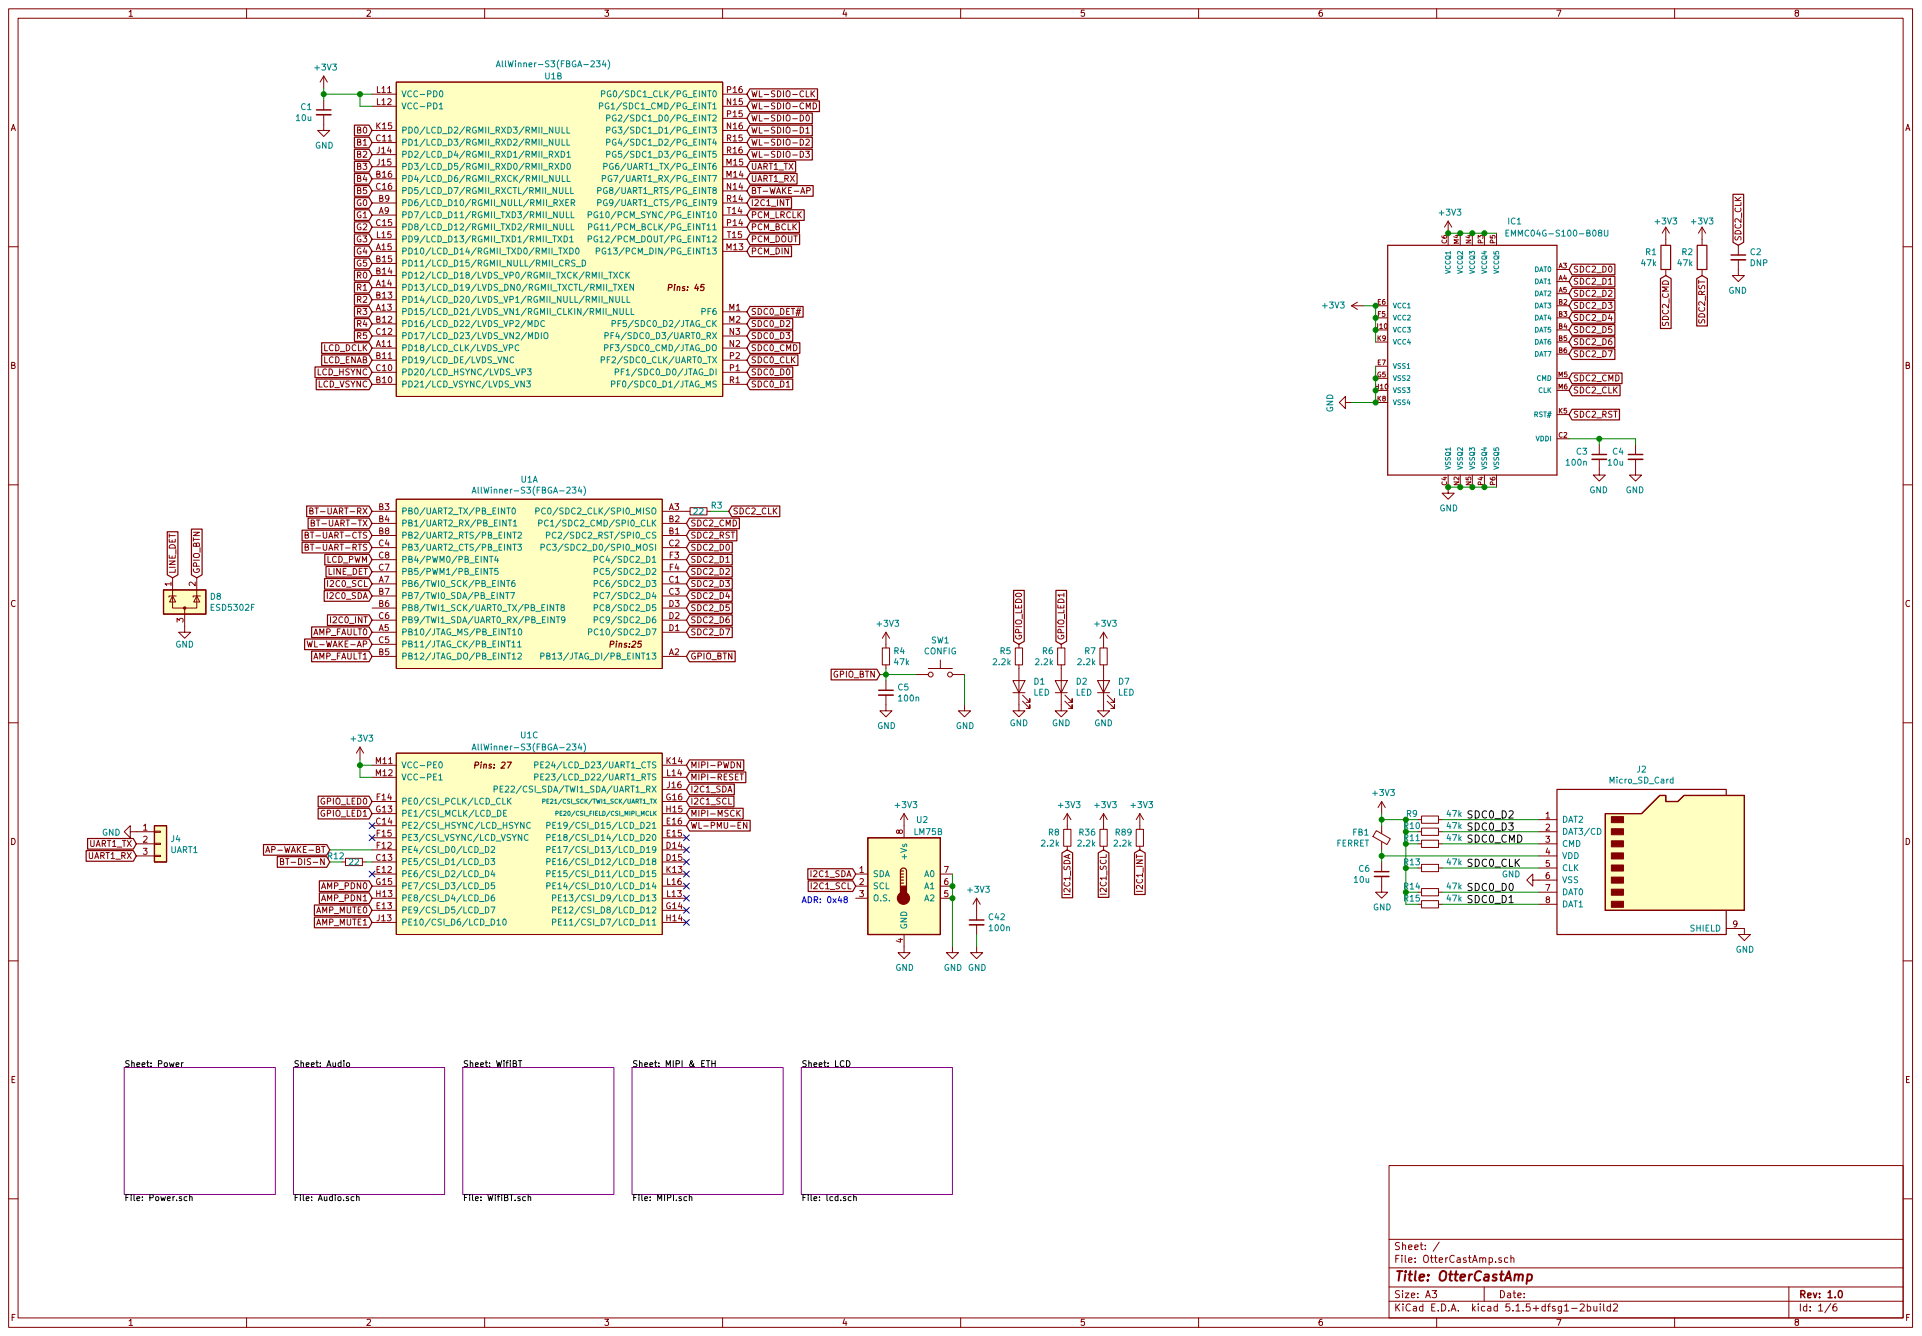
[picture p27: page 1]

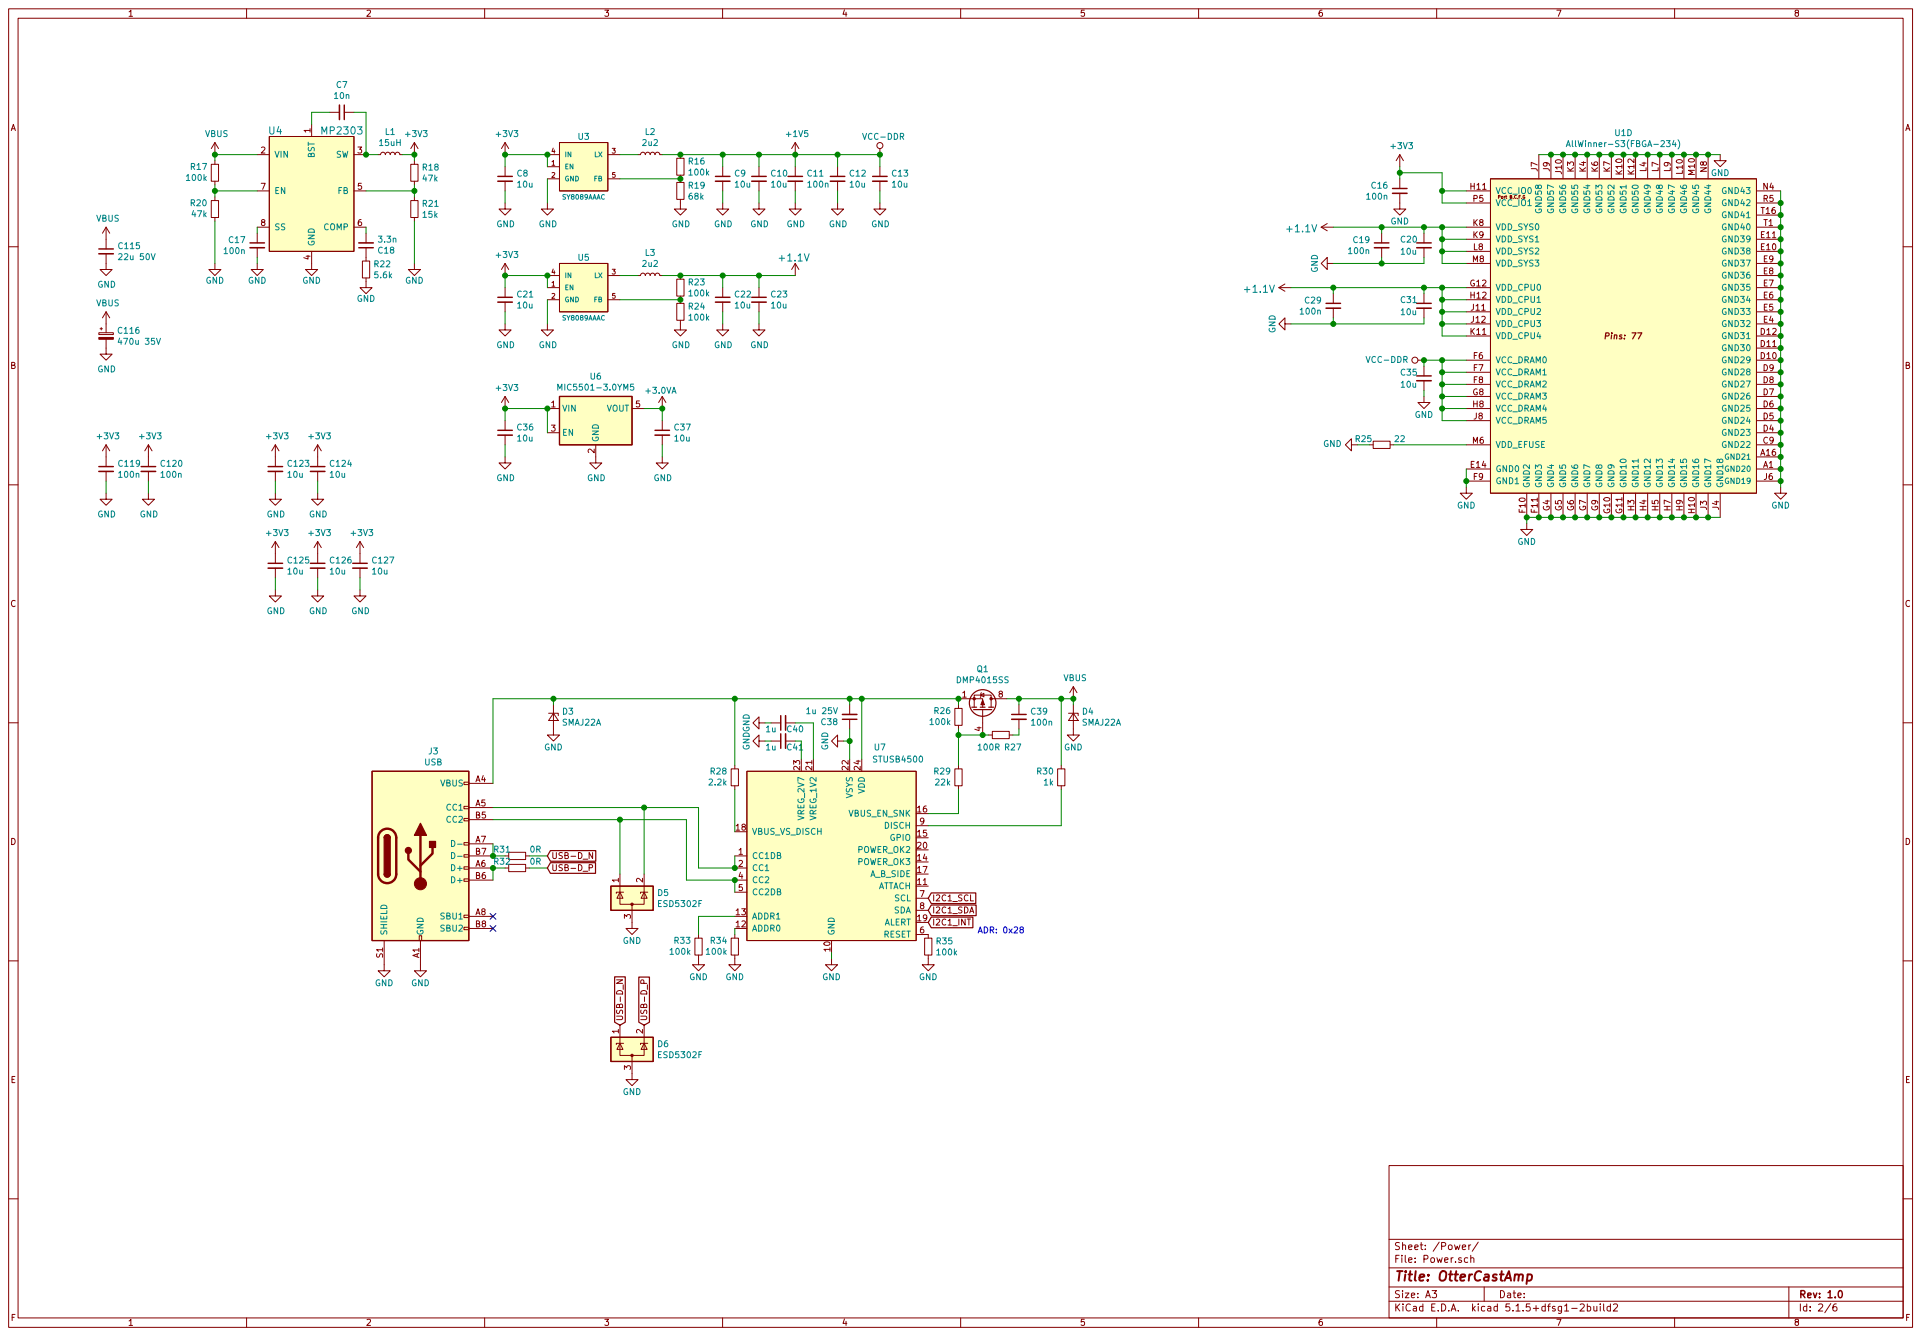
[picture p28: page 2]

4 FB 5 COMP 6 EN 7 SS 8 U4 MP2303
100kGND

2 EN 3 VOUT 5 U6 MIC5501-3.0YM5 GND GND

File: Power.sch Sheet: /Power/
Id: 2/6 Title: OtterCastAmp

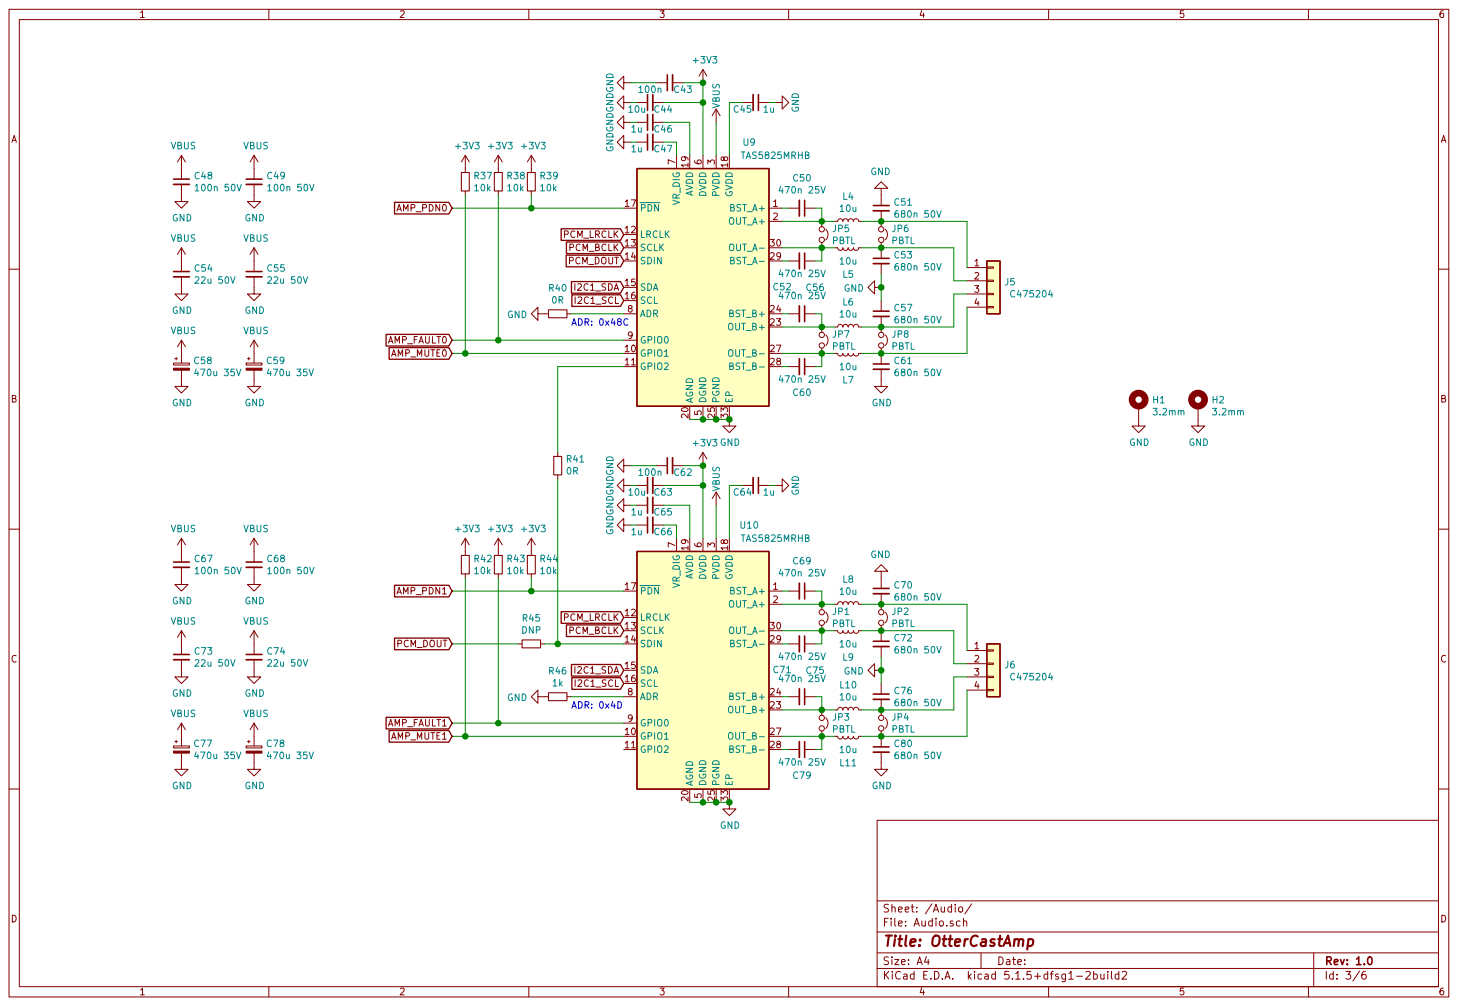
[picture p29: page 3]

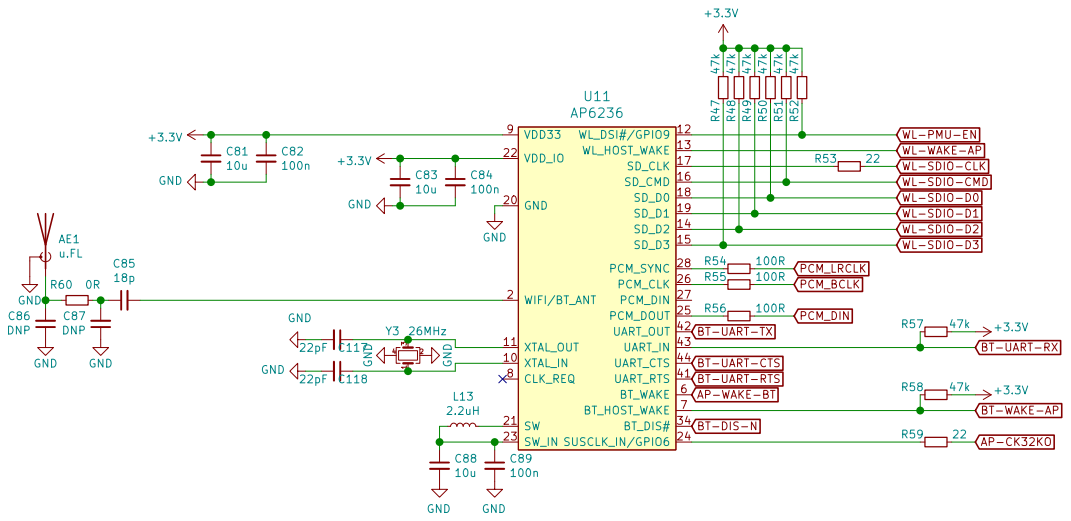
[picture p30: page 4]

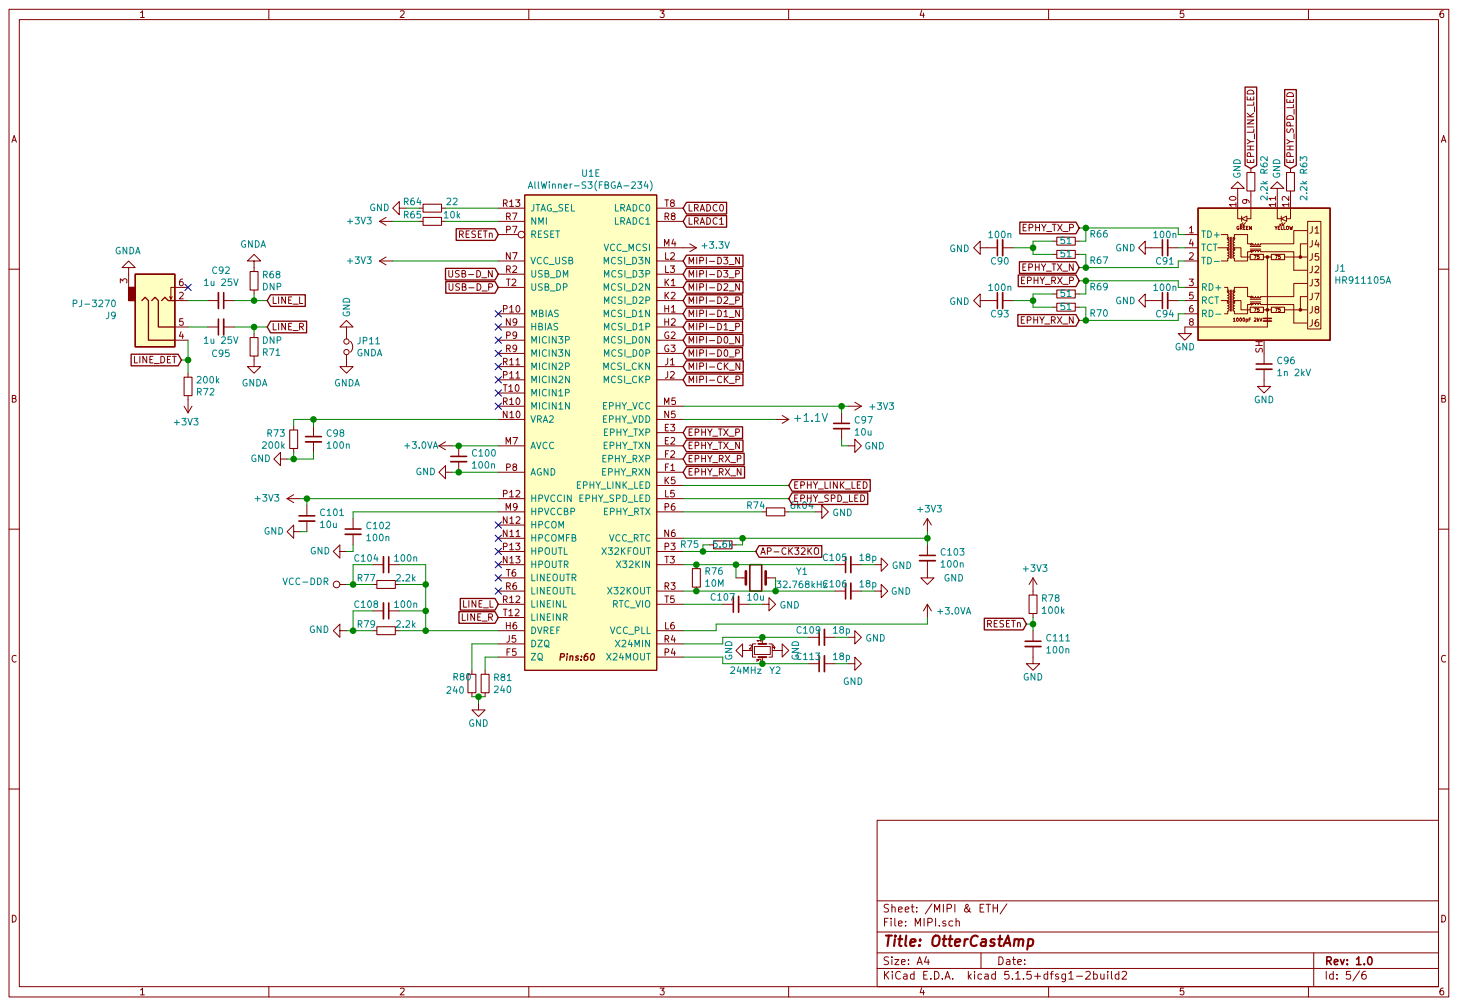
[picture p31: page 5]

File: MIPI.sch Sheet: /MIPI & ETH/ C102

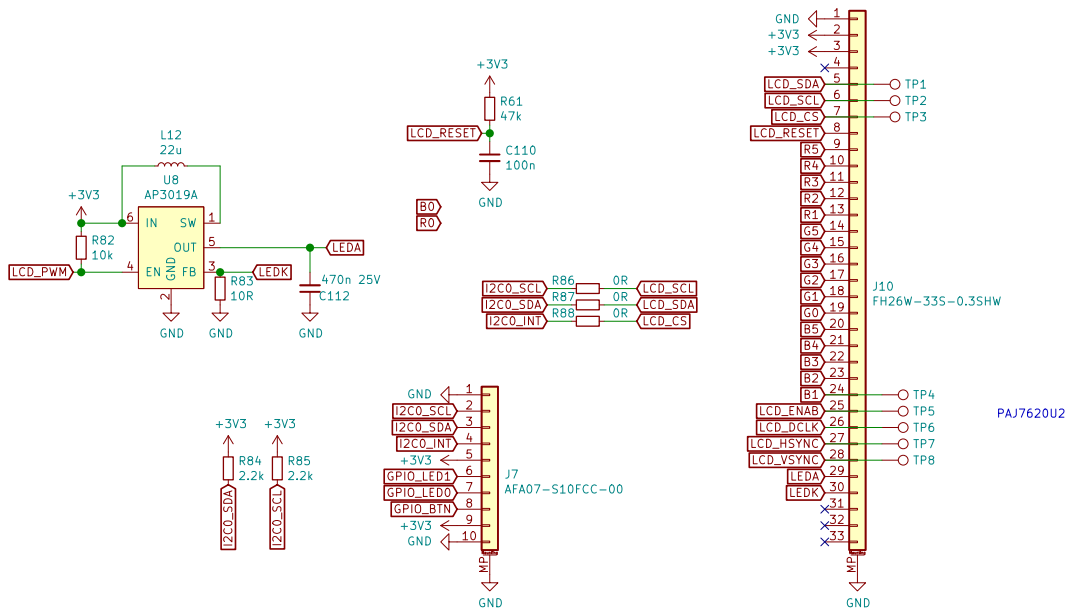
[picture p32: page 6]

File: lcd.sch Sheet: /LCD/ GND

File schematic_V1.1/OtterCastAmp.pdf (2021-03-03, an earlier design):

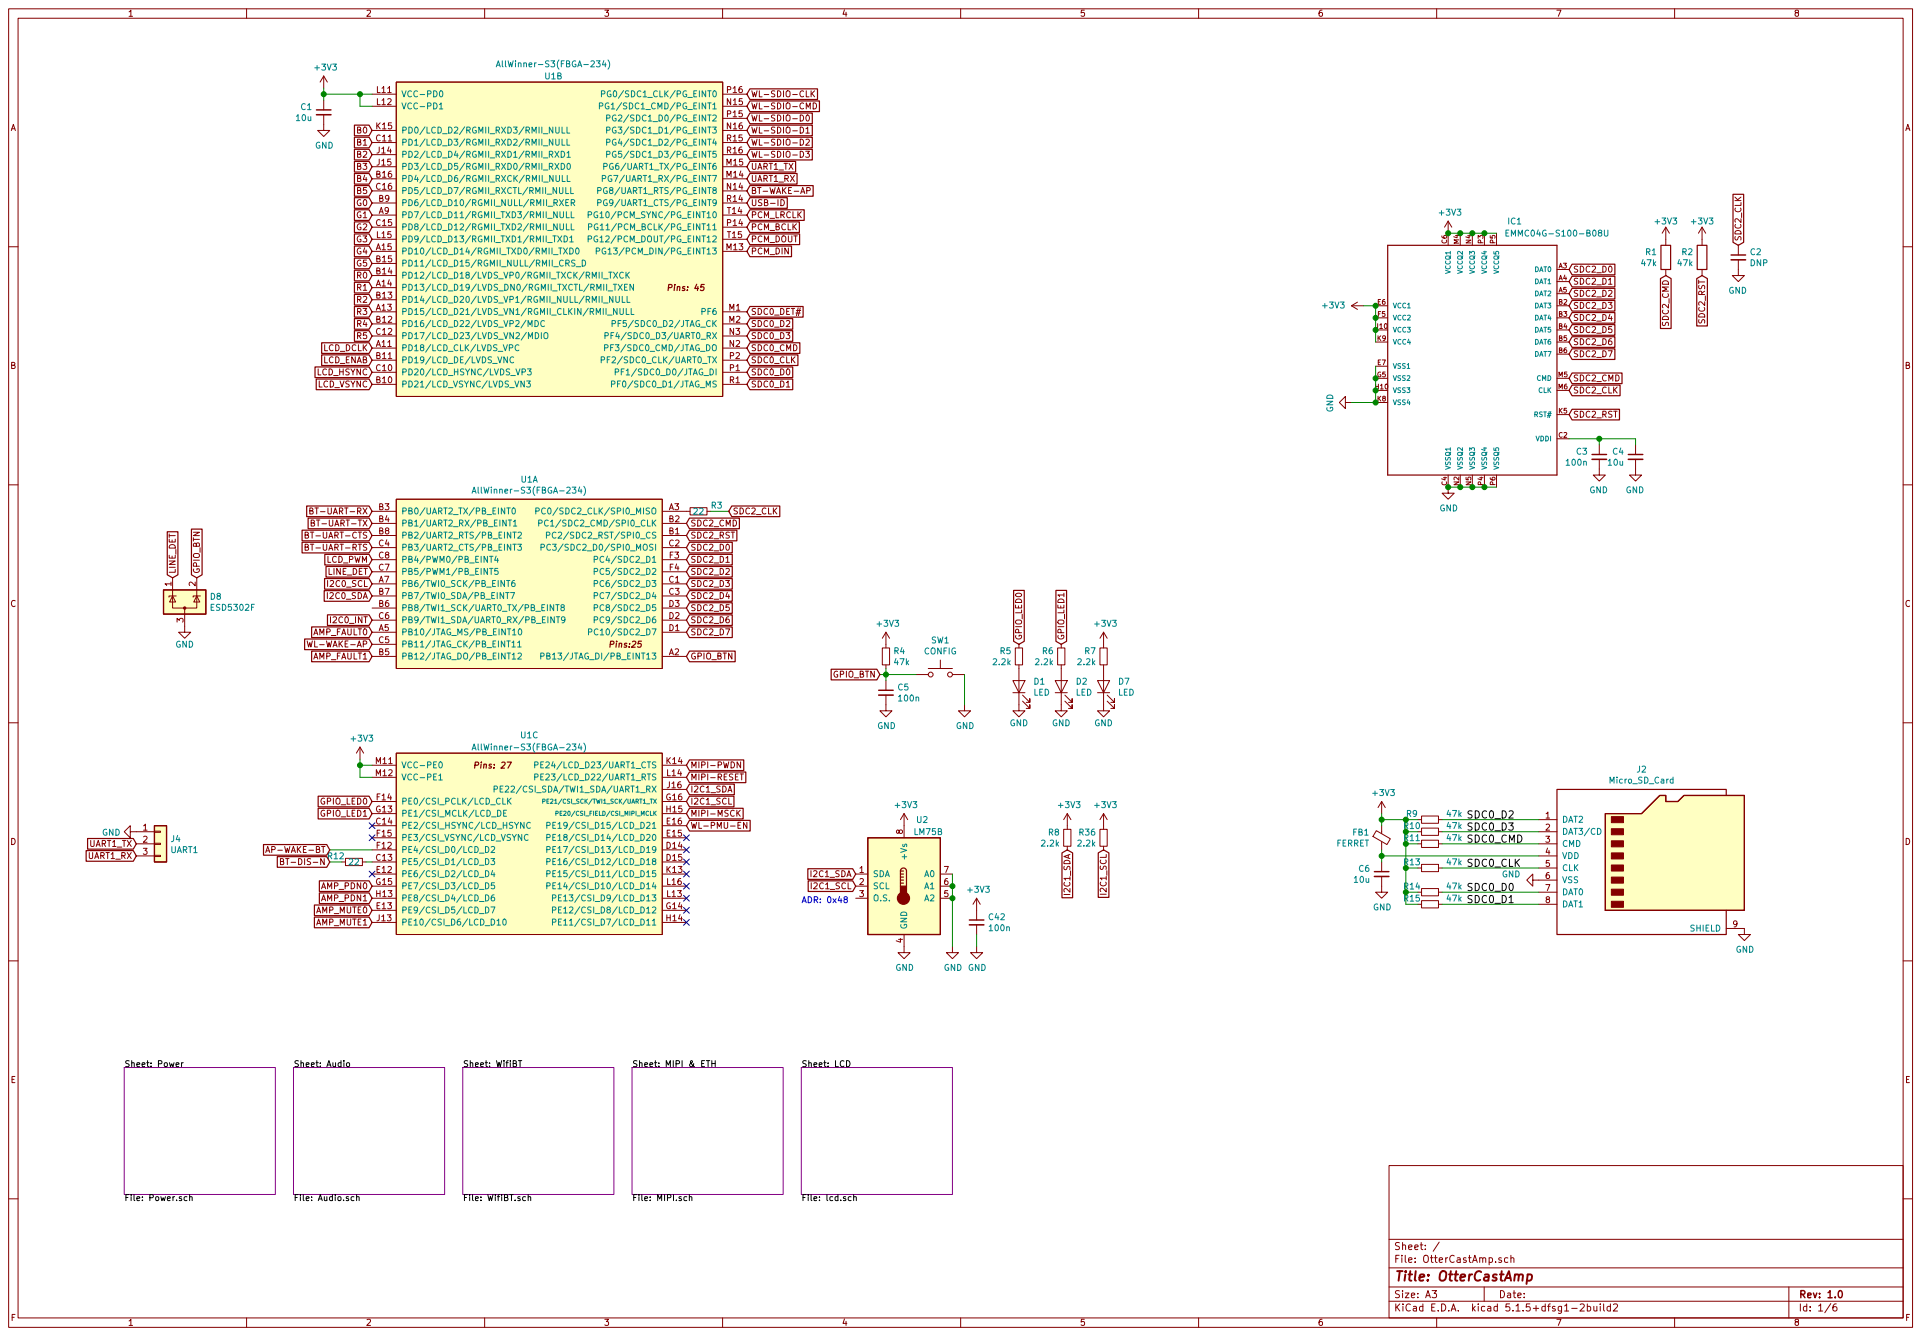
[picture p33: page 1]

WL-SDIO-CLK
SDC0_D0 SDC0_D1 SDC0_CLK UART1_RX WL-SDIO-CMD
BT-WAKE-AP WL-SDIO-D0 WL-SDIO-D1 WL-SDIO-D2

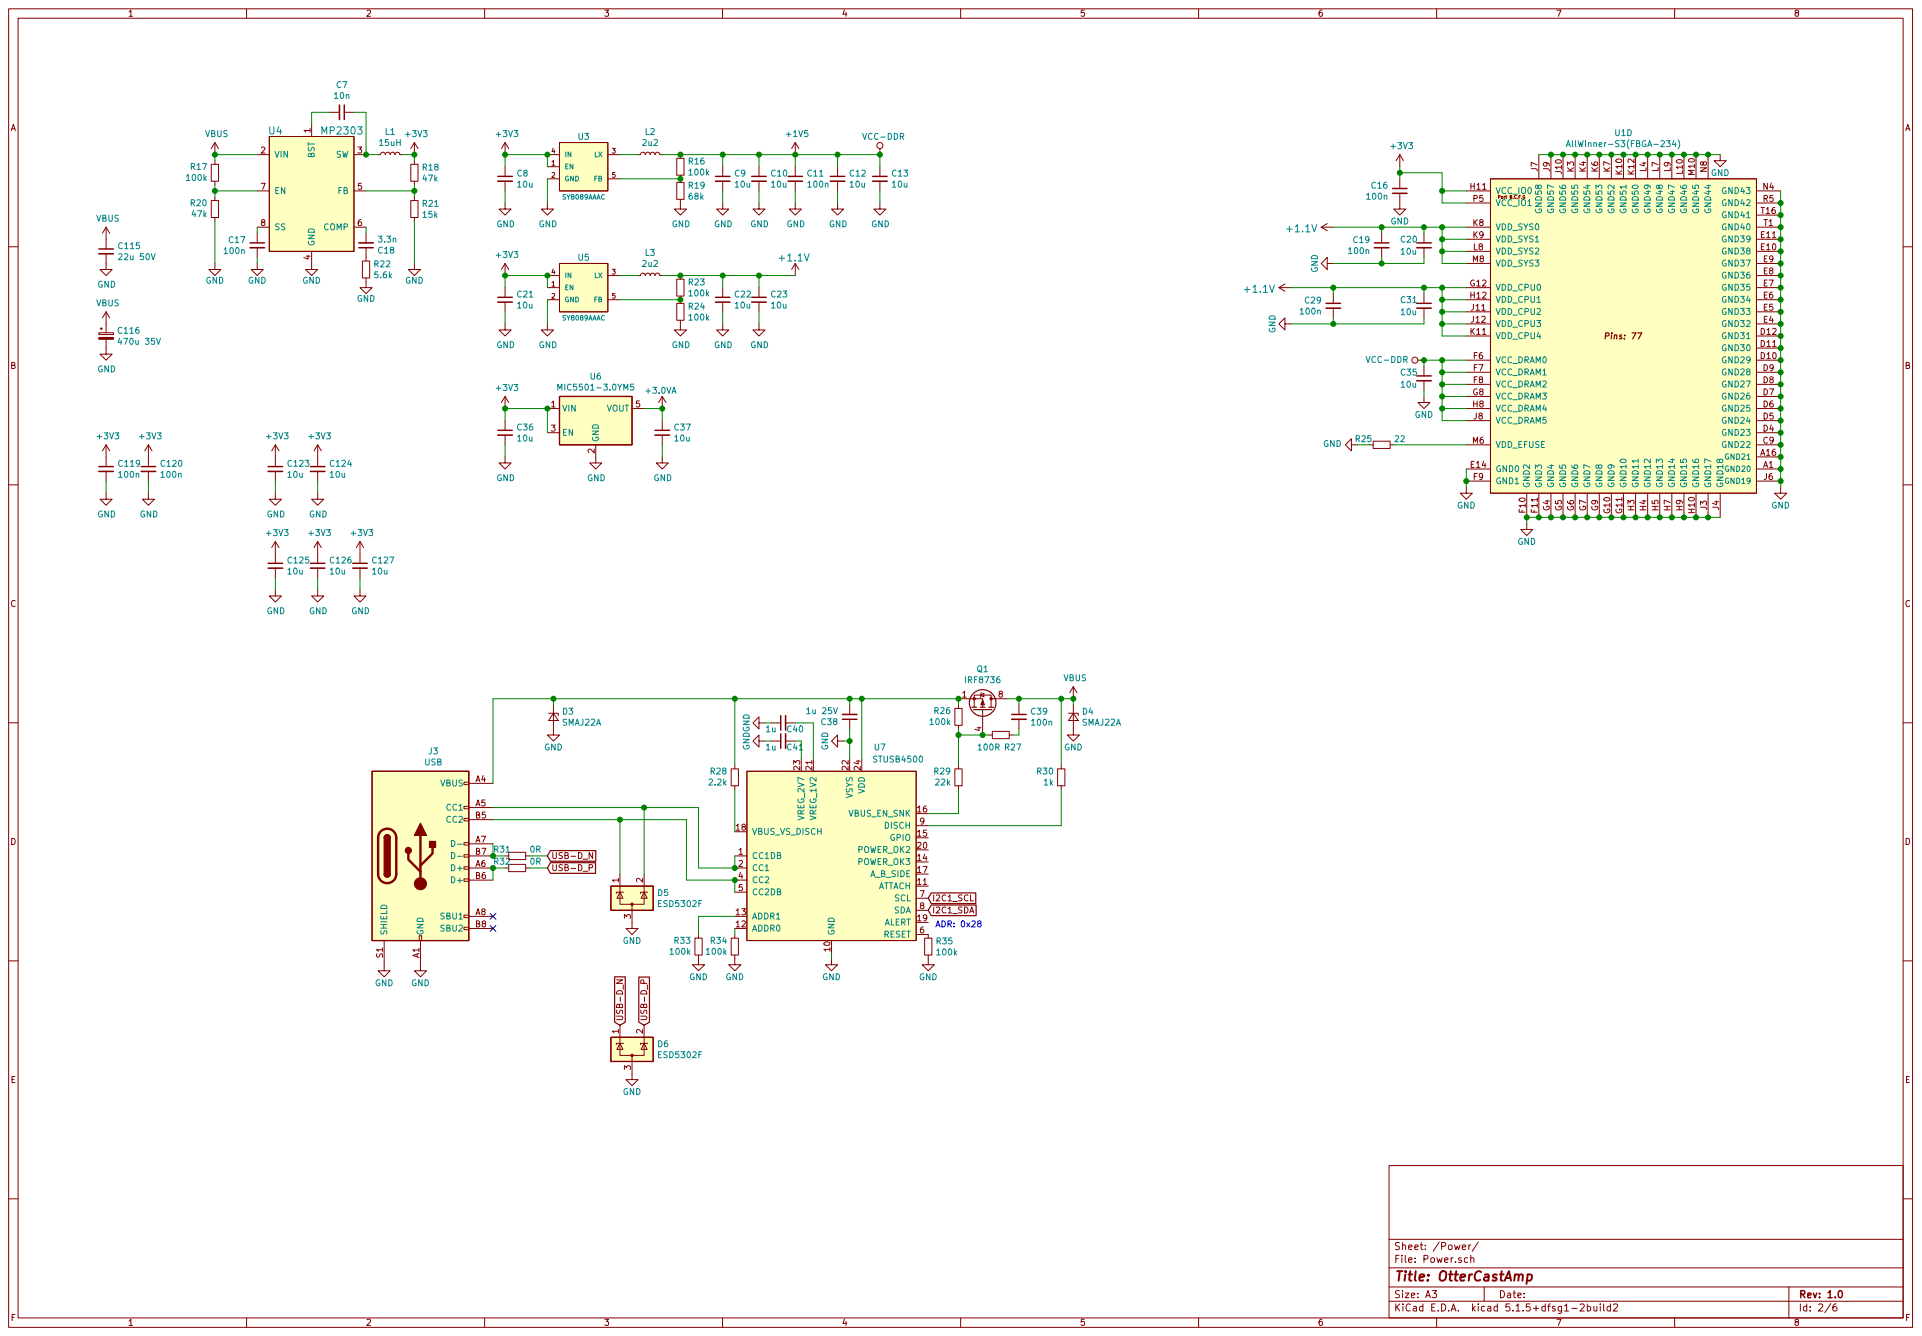
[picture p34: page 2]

4 FB 5 COMP 6 EN 7 SS 8 U4 MP2303
100kGND

File: Power.sch Sheet: /Power/
Id: 2/6 Title: OtterCastAmp


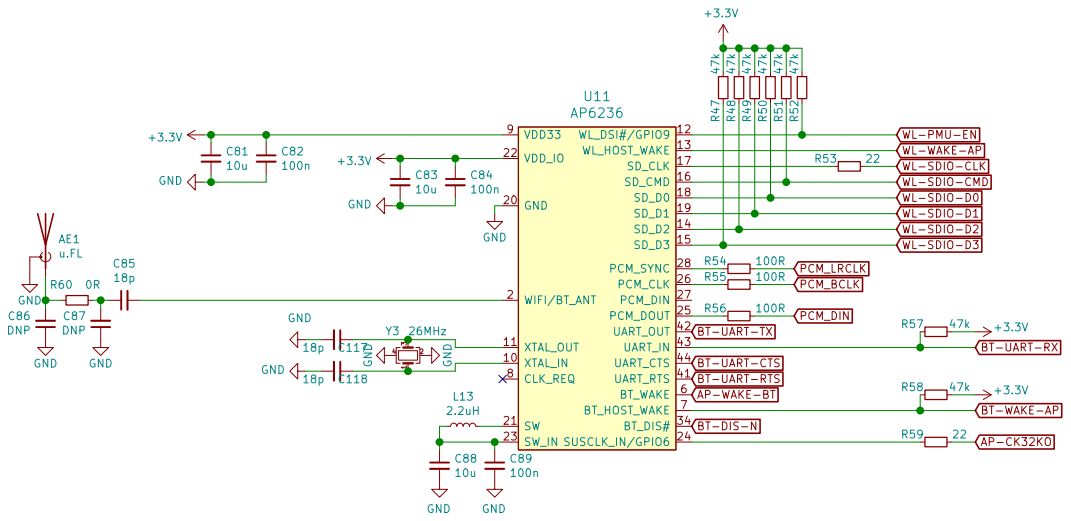
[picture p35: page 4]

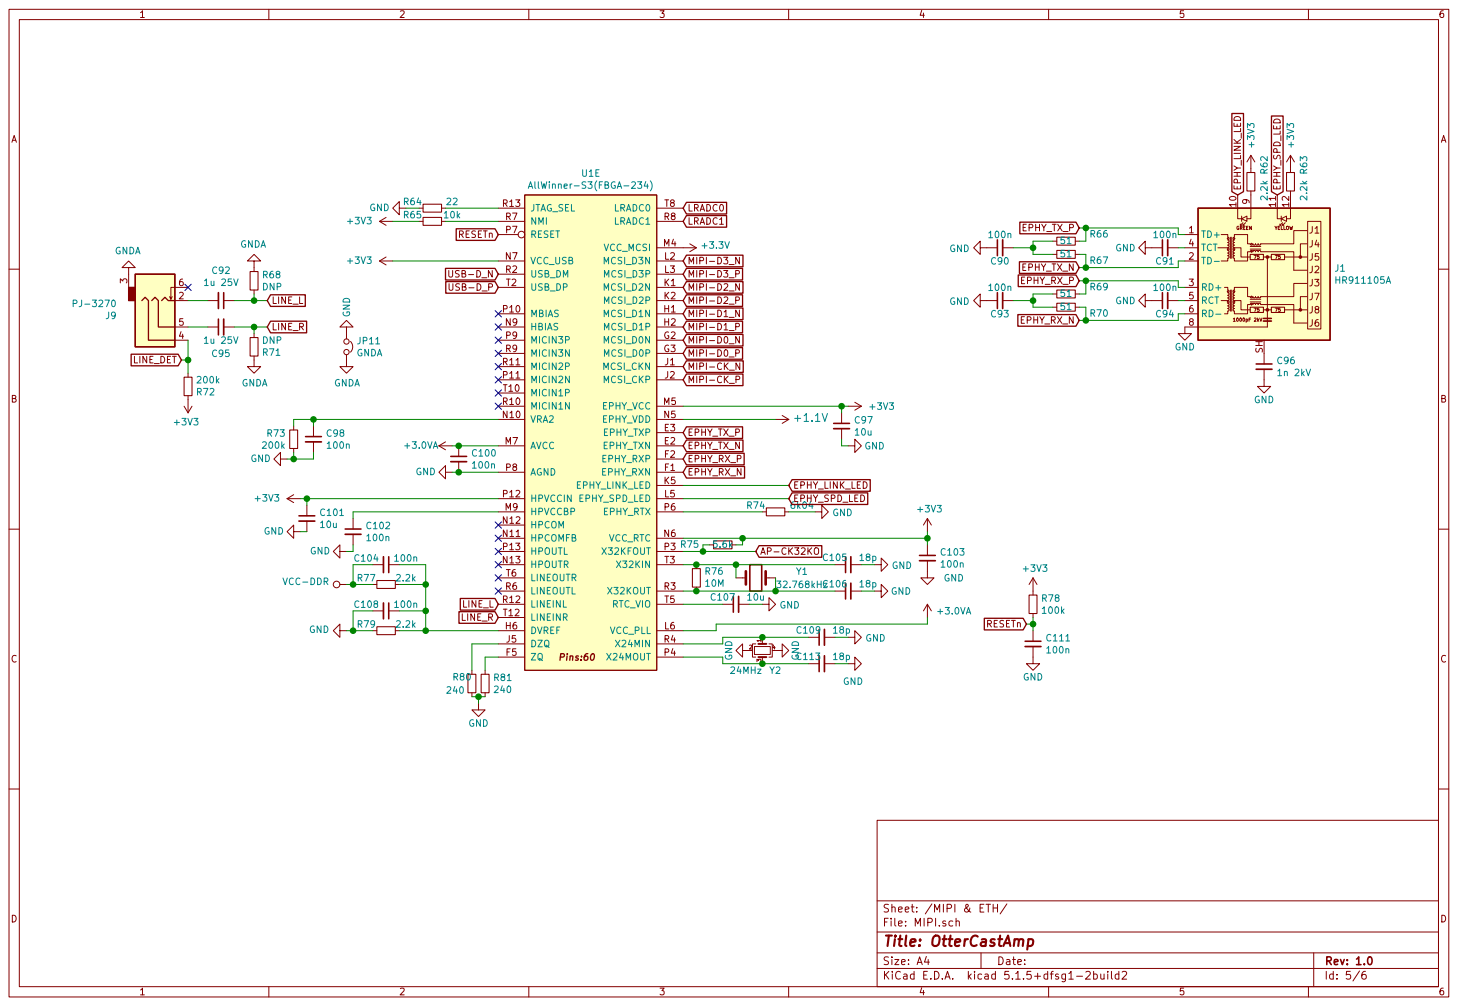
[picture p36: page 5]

File: MIPI.sch Sheet: /MIPI & ETH/ C102

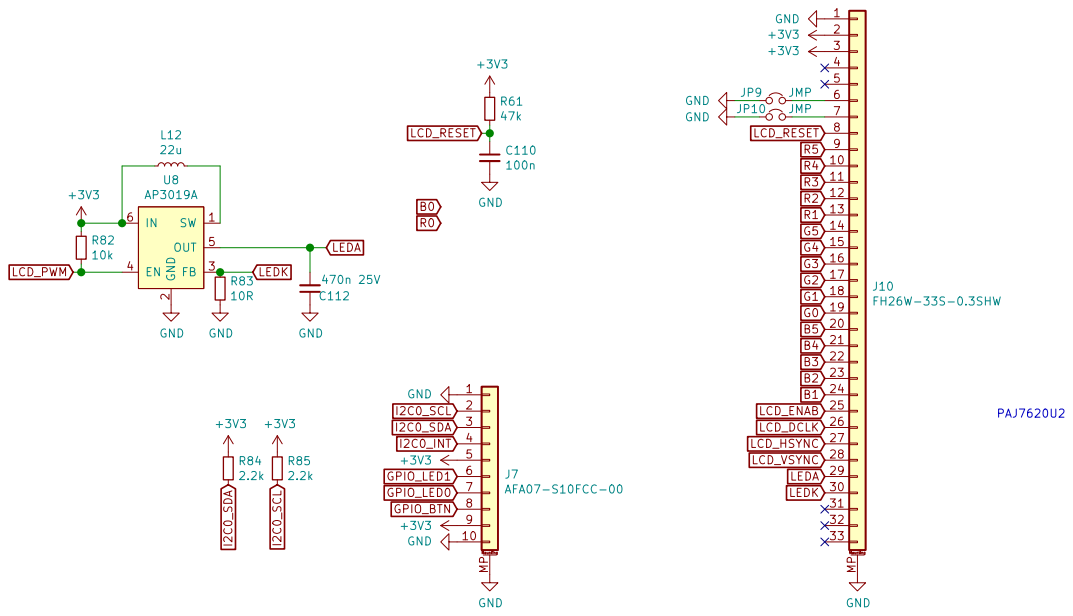
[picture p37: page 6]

File: lcd.sch Sheet: /LCD/
Id: 6/6 Title: OtterCastAmp

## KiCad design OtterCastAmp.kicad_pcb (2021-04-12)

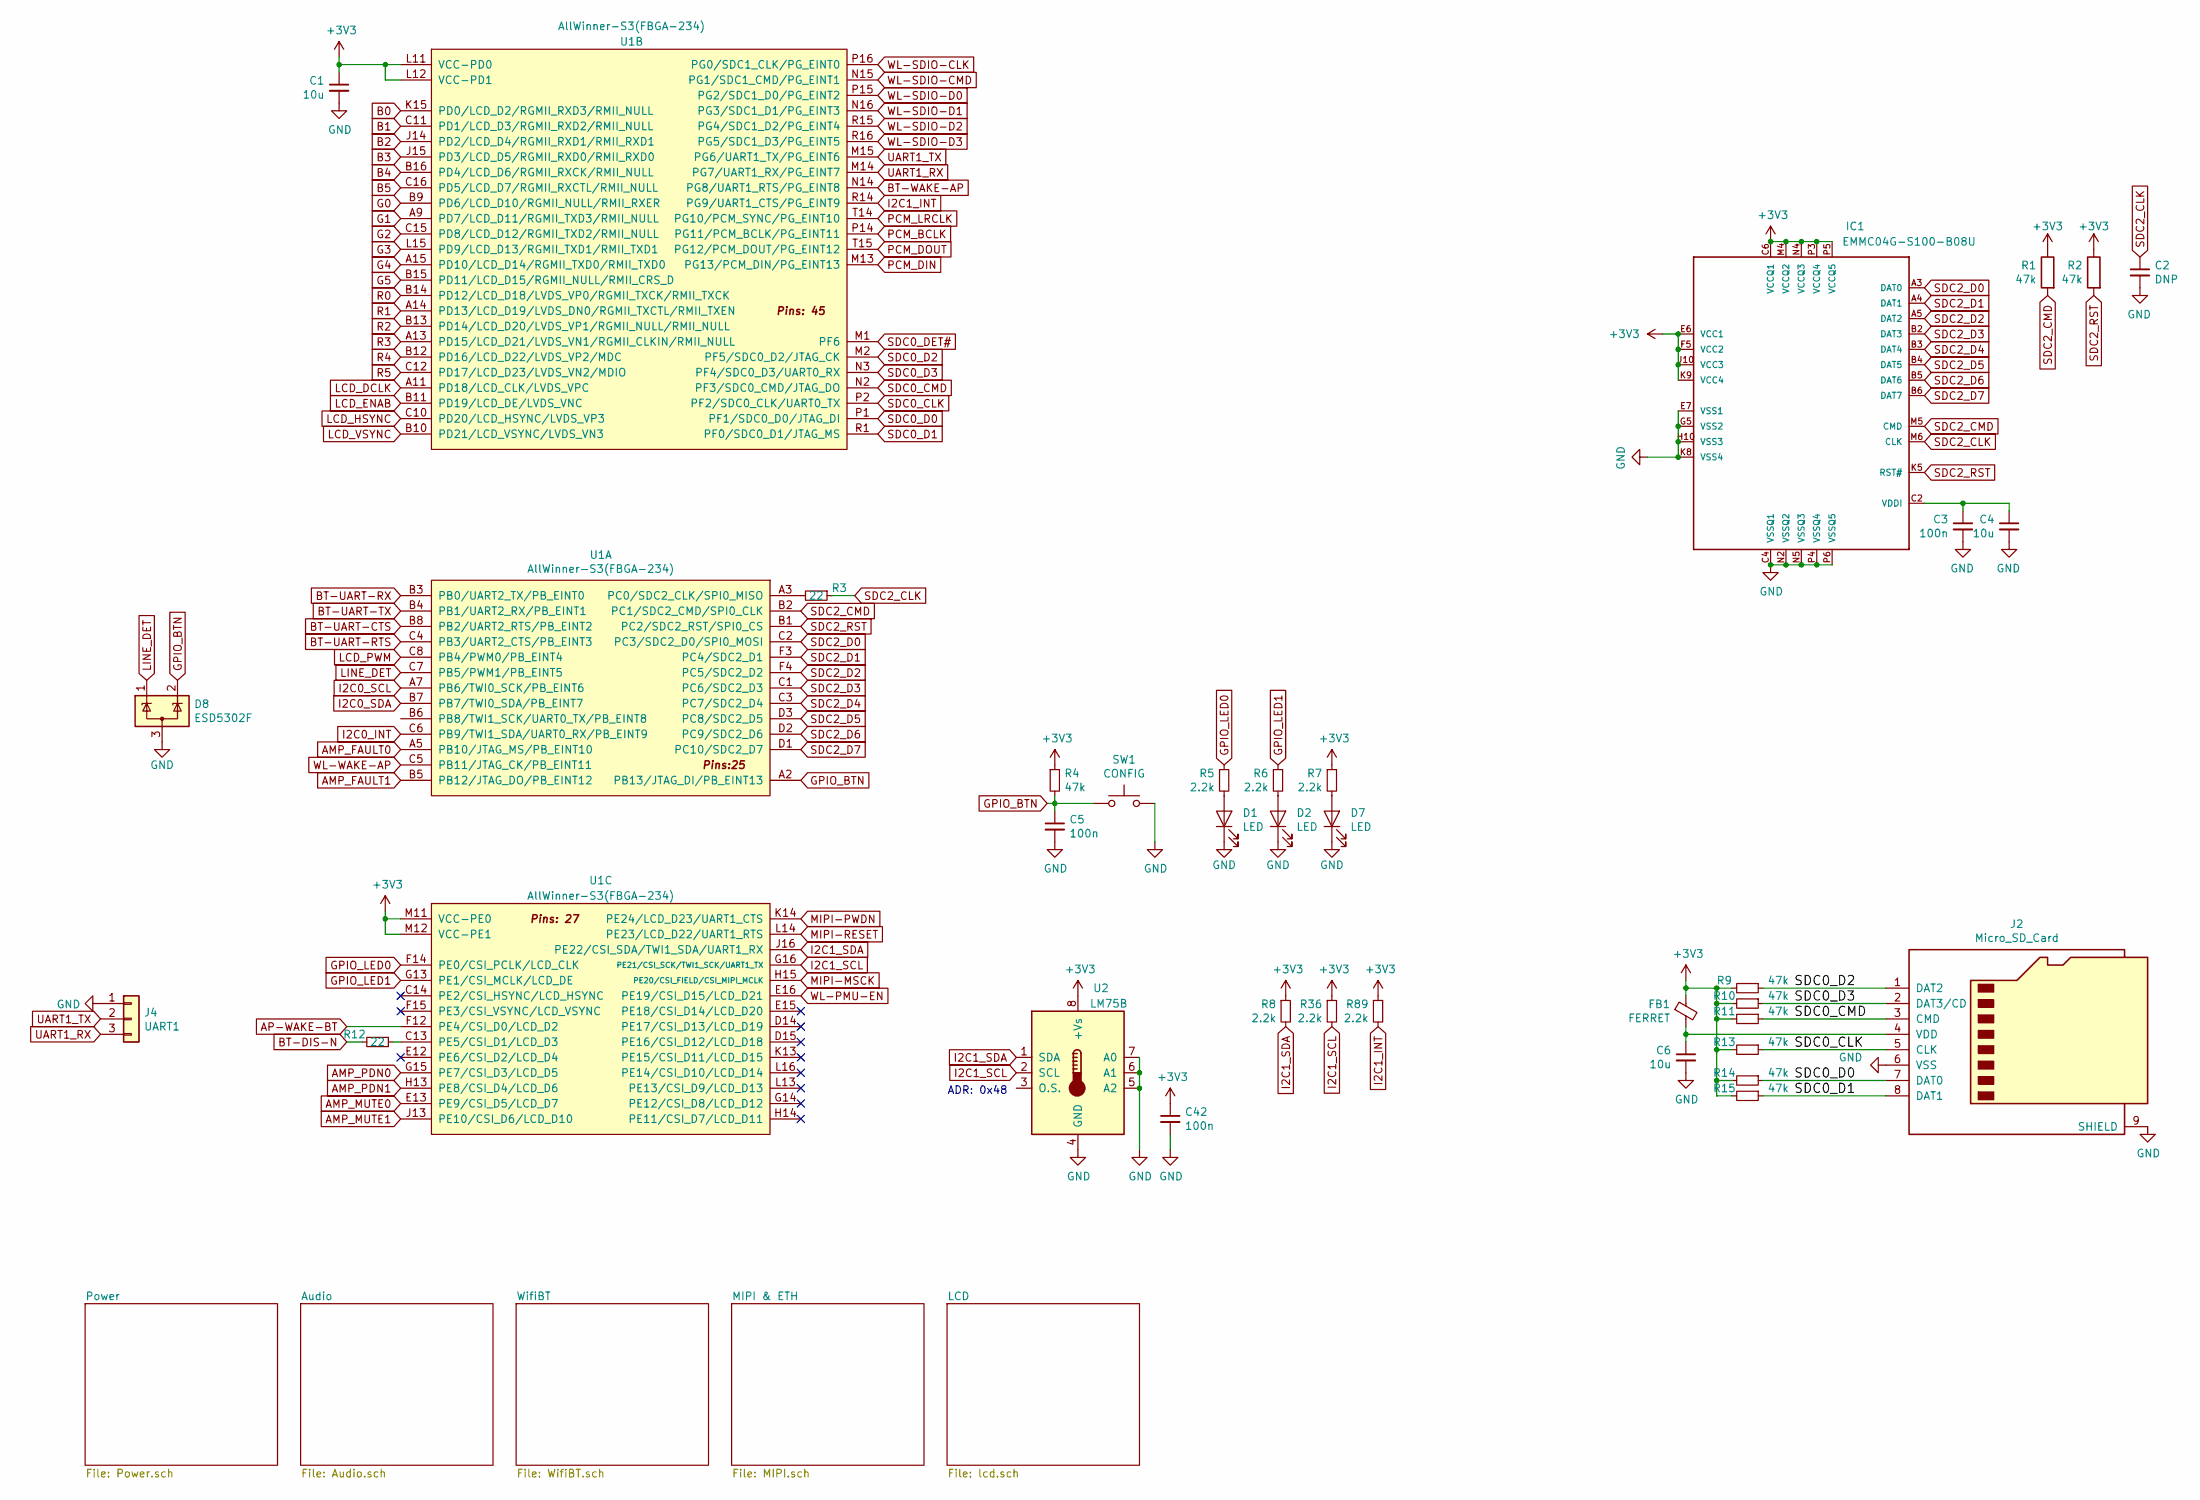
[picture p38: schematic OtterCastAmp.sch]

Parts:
C1, C4, C6: 10u; C_0603
C2: DNP; C_0402
C3, C5, C42: 100n; C_0402
D1, D2, D7: LED; LED_0603_1608Metric
D8: ESD5302F; SOT-23
FB1: FERRET; R_0805
IC1: EMMC04G-S100-B08U; MICRON_EMMC_153
J2: Micro_SD_Card; SUNTECH_ST-TF-003A
J4: UART1; PinHeader_1x03_P2.54mm_Vertical
R1, R2, R4, R9, R10, R11, R13, R14, R15: 47k; R_0402
R3, R12: 22; R_0402
R5, R6, R7, R8, R36, R89: 2.2k; R_0402
SW1: CONFIG; SW_SPST_EVQP7C
U1: AllWinner-S3(FBGA-234); FBGA-234(Pitch-0.65mm_Pad-0.3mm_11x11x1.08mm)
U2: LM75B; VSSOP-8_3.0x3.0mm_P0.65mm

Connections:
AMP_FAULT0: U1.A5 (PB10/JTAG_MS/PB_EINT10); also elsewhere on the board
AMP_FAULT1: U1.B5 (PB12/JTAG_DO/PB_EINT12); also elsewhere on the board
AMP_MUTE0: U1.E13 (PE9/CSI_D5/LCD_D7); also elsewhere on the board
AMP_MUTE1: U1.J13 (PE10/CSI_D6/LCD_D10); also elsewhere on the board
AMP_PDN0: U1.G15 (PE7/CSI_D3/LCD_D5); also elsewhere on the board
AMP_PDN1: U1.H13 (PE8/CSI_D4/LCD_D6); also elsewhere on the board
AP-WAKE-BT: U1.F12 (PE4/CSI_D0/LCD_D2); also elsewhere on the board
B0: U1.K15 (PD0/LCD_D2/RGMII_RXD3/RMII_NULL)
B1: U1.C11 (PD1/LCD_D3/RGMII_RXD2/RMII_NULL); also elsewhere on the board
B2: U1.J14 (PD2/LCD_D4/RGMII_RXD1/RMII_RXD1); also elsewhere on the board
B3: U1.J15 (PD3/LCD_D5/RGMII_RXD0/RMII_RXD0); also elsewhere on the board
B4: U1.B16 (PD4/LCD_D6/RGMII_RXCK/RMII_NULL); also elsewhere on the board
B5: U1.C16 (PD5/LCD_D7/RGMII_RXCTL/RMII_NULL); also elsewhere on the board
BT-DIS-N: R12.2; also elsewhere on the board
BT-UART-CTS: U1.B8 (PB2/UART2_RTS/PB_EINT2); also elsewhere on the board
BT-UART-RTS: U1.C4 (PB3/UART2_CTS/PB_EINT3); also elsewhere on the board
BT-UART-RX: U1.B3 (PB0/UART2_TX/PB_EINT0); also elsewhere on the board
BT-UART-TX: U1.B4 (PB1/UART2_RX/PB_EINT1); also elsewhere on the board
BT-WAKE-AP: U1.N14 (PG8/UART1_RTS/PG_EINT8); also elsewhere on the board
G0: U1.B9 (PD6/LCD_D10/RGMII_NULL/RMII_RXER); also elsewhere on the board
G1: U1.A9 (PD7/LCD_D11/RGMII_TXD3/RMII_NULL); also elsewhere on the board
G2: U1.C15 (PD8/LCD_D12/RGMII_TXD2/RMII_NULL); also elsewhere on the board
G3: U1.L15 (PD9/LCD_D13/RGMII_TXD1/RMII_TXD1); also elsewhere on the board
G4: U1.A15 (PD10/LCD_D14/RGMII_TXD0/RMII_TXD0); also elsewhere on the board
G5: U1.B15 (PD11/LCD_D15/RGMII_NULL/RMII_CRS_D); also elsewhere on the board
GND: C1.2, C2.2, C3.2, C4.2, C5.2, C6.2, C42.2, D1.1 (K), D2.1 (K), D7.1 (K), D8.3 (A), IC1.C4 (VSSQ1), IC1.E7 (VSS1), IC1.G5 (VSS2), IC1.H10 (VSS3), IC1.K8 (VSS4), IC1.N2 (VSSQ2), IC1.N5 (VSSQ3), IC1.P4 (VSSQ4), IC1.P6 (VSSQ5), J2.6 (VSS), J2.9 (SHIELD), J4.1, SW1.2, U2.4 (GND), U2.5 (A2), U2.6 (A1), U2.7 (A0); also elsewhere on the board
GPIO_BTN: C5.1, D8.2 (K), R4.2, SW1.1, U1.A2 (PB13/JTAG_DI/PB_EINT13); also elsewhere on the board
GPIO_LED0: R5.1, U1.F14 (PE0/CSI_PCLK/LCD_CLK); also elsewhere on the board
GPIO_LED1: R6.1, U1.G13 (PE1/CSI_MCLK/LCD_DE); also elsewhere on the board
I2C0_INT: U1.C6 (PB9/TWI1_SDA/UART0_RX/PB_EINT9); also elsewhere on the board
I2C0_SCL: U1.A7 (PB6/TWI0_SCK/PB_EINT6); also elsewhere on the board
I2C0_SDA: U1.B7 (PB7/TWI0_SDA/PB_EINT7); also elsewhere on the board
I2C1_INT: R89.2, U1.R14 (PG9/UART1_CTS/PG_EINT9); also elsewhere on the board
I2C1_SCL: R36.2, U1.G16 (PE21/CSI_SCK/TWI1_SCK/UART1_TX), U2.2 (SCL); also elsewhere on the board
I2C1_SDA: R8.2, U1.J16 (PE22/CSI_SDA/TWI1_SDA/UART1_RX), U2.1 (SDA); also elsewhere on the board
LCD_DCLK: U1.A11 (PD18/LCD_CLK/LVDS_VPC); also elsewhere on the board
LCD_ENAB: U1.B11 (PD19/LCD_DE/LVDS_VNC); also elsewhere on the board
LCD_HSYNC: U1.C10 (PD20/LCD_HSYNC/LVDS_VP3); also elsewhere on the board
LCD_PWM: U1.C8 (PB4/PWM0/PB_EINT4); also elsewhere on the board
LCD_VSYNC: U1.B10 (PD21/LCD_VSYNC/LVDS_VN3); also elsewhere on the board
LINE_DET: D8.1 (K), U1.C7 (PB5/PWM1/PB_EINT5); also elsewhere on the board
MIPI-MSCK: U1.H15 (PE20/CSI_FIELD/CSI_MIPI_MCLK)
MIPI-PWDN: U1.K14 (PE24/LCD_D23/UART1_CTS)
MIPI-RESET: U1.L14 (PE23/LCD_D22/UART1_RTS)
unnamed: C3.1, C4.1, IC1.C2 (VDDI)
unnamed: C6.1, FB1.2, J2.4 (VDD)
unnamed: D1.2 (A), R5.2
unnamed: D2.2 (A), R6.2
unnamed 141: D7.2 (A), R7.2; also elsewhere on the board
unnamed: R3.2, U1.A3 (PC0/SDC2_CLK/SPI0_MISO)
unnamed: R12.1, U1.C13 (PE5/CSI_D1/LCD_D3)
PCM_BCLK: U1.P14 (PG11/PCM_BCLK/PG_EINT11); also elsewhere on the board
PCM_DIN: U1.M13 (PG13/PCM_DIN/PG_EINT13); also elsewhere on the board
PCM_DOUT: U1.T15 (PG12/PCM_DOUT/PG_EINT12); also elsewhere on the board
PCM_LRCLK: U1.T14 (PG10/PCM_SYNC/PG_EINT10); also elsewhere on the board
R0: U1.B14 (PD12/LCD_D18/LVDS_VP0/RGMII_TXCK/RMII_T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)
R1: U1.A14 (PD13/LCD_D19/LVDS_DN0/RGMII_TXCTL/RMII_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); also elsewhere on the board
R2: U1.B13 (PD14/LCD_D20/LVDS_VP1/RGMII_NULL/RMII_N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); also elsewhere on the board
R3: U1.A13 (PD15/LCD_D21/LVDS_VN1/RGMII_CLKIN/RMII_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); also elsewhere on the board
R4: U1.B12 (PD16/LCD_D22/LVDS_VP2/MDC); also elsewhere on the board
R5: U1.C12 (PD17/LCD_D23/LVDS_VN2/MDIO); also elsewhere on the board
SDC0_CLK: J2.5 (CLK), R13.1, U1.P2 (PF2/SDC0_CLK/UART0_TX)
SDC0_CMD: J2.3 (CMD), R11.1, U1.N2 (PF3/SDC0_CMD/JTAG_DO)
SDC0_D0: J2.7 (DAT0), R14.1, U1.P1 (PF1/SDC0_D0/JTAG_DI)
SDC0_D1: J2.8 (DAT1), R15.1, U1.R1 (PF0/SDC0_D1/JTAG_MS)
SDC0_D2: J2.1 (DAT2), R9.1, U1.M2 (PF5/SDC0_D2/JTAG_CK)
SDC0_D3: J2.2 (DAT3/CD), R10.1, U1.N3 (PF4/SDC0_D3/UART0_RX)
SDC0_DET#: U1.M1 (PF6)
SDC2_CLK: C2.1, IC1.M6 (CLK), R3.1
SDC2_CMD: IC1.M5 (CMD), R1.2, U1.B2 (PC1/SDC2_CMD/SPI0_CLK)
SDC2_D0: IC1.A3 (DAT0), U1.C2 (PC3/SDC2_D0/SPI0_MOSI)
SDC2_D1: IC1.A4 (DAT1), U1.F3 (PC4/SDC2_D1)
SDC2_D2: IC1.A5 (DAT2), U1.F4 (PC5/SDC2_D2)
SDC2_D3: IC1.B2 (DAT3), U1.C1 (PC6/SDC2_D3)
SDC2_D4: IC1.B3 (DAT4), U1.C3 (PC7/SDC2_D4)
SDC2_D5: IC1.B4 (DAT5), U1.D3 (PC8/SDC2_D5)
SDC2_D6: IC1.B5 (DAT6), U1.D2 (PC9/SDC2_D6)
SDC2_D7: IC1.B6 (DAT7), U1.D1 (PC10/SDC2_D7)
SDC2_RST: IC1.K5 (RST#), R2.2, U1.B1 (PC2/SDC2_RST/SPI0_CS)
UART1_RX: J4.3, U1.M14 (PG7/UART1_RX/PG_EINT7)
UART1_TX: J4.2, U1.M15 (PG6/UART1_TX/PG_EINT6)
WL-PMU-EN: U1.E16 (PE19/CSI_D15/LCD_D21); also elsewhere on the board
WL-SDIO-CLK: U1.P16 (PG0/SDC1_CLK/PG_EINT0); also elsewhere on the board
WL-SDIO-CMD: U1.N15 (PG1/SDC1_CMD/PG_EINT1); also elsewhere on the board
WL-SDIO-D0: U1.P15 (PG2/SDC1_D0/PG_EINT2); also elsewhere on the board
WL-SDIO-D1: U1.N16 (PG3/SDC1_D1/PG_EINT3); also elsewhere on the board
WL-SDIO-D2: U1.R15 (PG4/SDC1_D2/PG_EINT4); also elsewhere on the board
WL-SDIO-D3: U1.R16 (PG5/SDC1_D3/PG_EINT5); also elsewhere on the board
WL-WAKE-AP: U1.C5 (PB11/JTAG_CK/PB_EINT11); also elsewhere on the board

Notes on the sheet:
ADR: 0x48

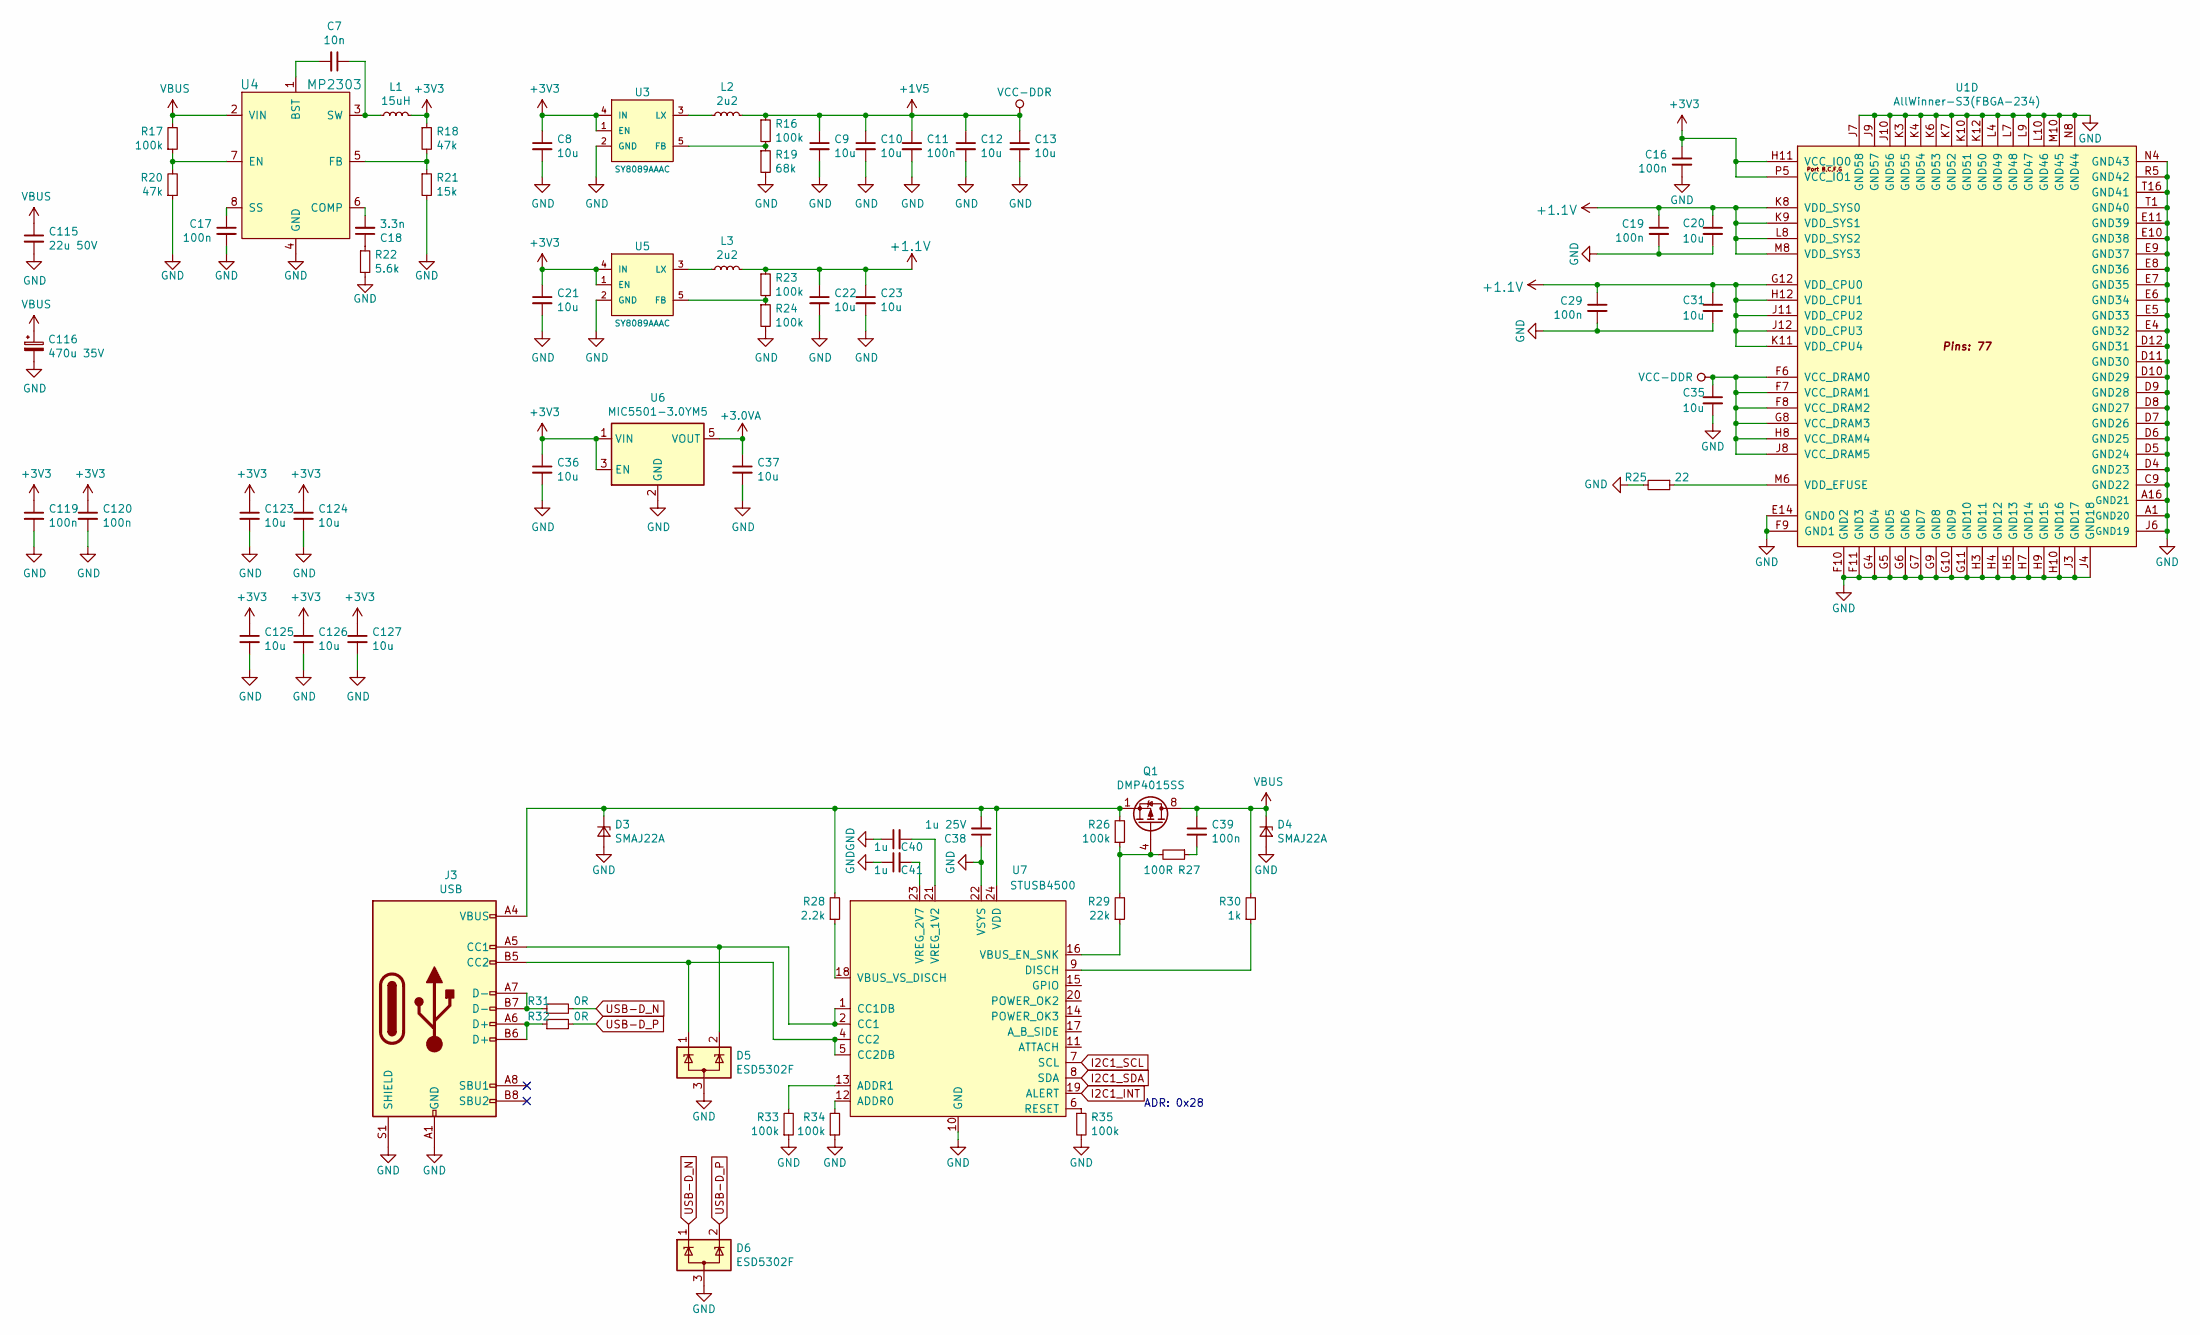
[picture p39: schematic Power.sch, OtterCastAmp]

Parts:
C7: 10n; C_0402
C8, C9, C10, C12, C13, C20, C21, C22, C23, C31, C35, C36, C37, C123, C124, C125, C126, C127: 10u; C_0603
C11, C16, C17, C19, C29, C39, C119, C120: 100n; C_0402
C18: 3.3n; C_0402
C38: 1u 25V; C_0603
C40, C41: 1u; C_0402
C115: 22u 50V; C_1206_3216Metric
C116: 470u 35V; CP_Elec_10x10.5
D3, D4: SMAJ22A; D_SMA
D5, D6: ESD5302F; SOT-23
J3: USB; USB-C 16Pin
L1: 15uH; L_10.4x10.4_H4.8
L2, L3: 2u2; Inductor_4040
Q1: DMP4015SS; SOIC-8_3.9x4.9mm_P1.27mm
R16, R17, R23, R24, R26, R33, R34, R35: 100k; R_0402
R18, R20: 47k; R_0402
R19: 68k; R_0402
R21: 15k; R_0402
R22: 5.6k; R_0402
R25: 22; R_0402
R27: 100R; R_0402
R28: 2.2k; R_0402
R29: 22k; R_0402
R30: 1k; R_0402
R31, R32: 0R; R_0402
U1: AllWinner-S3(FBGA-234); FBGA-234(Pitch-0.65mm_Pad-0.3mm_11x11x1.08mm)
U3, U5: SY8089AAAC; SOT-23-5
U4: MP2303; SOIC-8-1EP_3.9x4.9mm_P1.27mm_EP2.29x3mm
U6: MIC5501-3.0YM5; SOT-23-5
U7: STUSB4500; QFN-24-1EP_4x4mm_P0.5mm_EP2.7x2.7mm

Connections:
+1.1V: C19.1, C20.1, C22.1, C23.1, C29.1, C31.1, L3.2, R23.1, U1.G12 (VDD_CPU0), U1.H12 (VDD_CPU1), U1.J11 (VDD_CPU2), U1.J12 (VDD_CPU3), U1.K8 (VDD_SYS0), U1.K9 (VDD_SYS1), U1.K11 (VDD_CPU4), U1.L8 (VDD_SYS2), U1.M8 (VDD_SYS3); also elsewhere on the board
+1V5: C9.1, C10.1, C11.1, C12.1, C13.1, C35.1, L2.2, R16.1, U1.F6 (VCC_DRAM0), U1.F7 (VCC_DRAM1), U1.F8 (VCC_DRAM2), U1.G8 (VCC_DRAM3), U1.H8 (VCC_DRAM4), U1.J8 (VCC_DRAM5); also elsewhere on the board
+3.0VA: C37.1, U6.5 (VOUT); also elsewhere on the board
GND: C8.2, C9.2, C10.2, C11.2, C12.2, C13.2, C16.2, C17.2, C19.2, C20.2, C21.2, C22.2, C23.2, C29.2, C31.2, C35.2, C36.2, C37.2, C38.1, C40.1, C41.1, C115.2, C116.2, C119.2, C120.2, C123.2, C124.2, C125.2, C126.2, C127.2, D3.2 (A), D4.2 (A), D5.3 (A), D6.3 (A), J3.A1 (GND), J3.A12 (GND), J3.B1 (GND), J3.B12 (GND), J3.S1 (SHIELD), R19.2, R20.1, R21.2, R22.2, R24.2, R25.2, R33.1, R34.1, R35.2, U1.A1 (GND20), U1.A16 (GND21), U1.C9 (GND22), U1.D4 (GND23), U1.D5 (GND24), U1.D6 (GND25), U1.D7 (GND26), U1.D8 (GND27), U1.D9 (GND28), U1.D10 (GND29), U1.D11 (GND30), U1.D12 (GND31), U1.E4 (GND32), U1.E5 (GND33), U1.E6 (GND34), U1.E7 (GND35), U1.E8 (GND36), U1.E9 (GND37), U1.E10 (GND38), U1.E11 (GND39), U1.E14 (GND0), U1.F9 (GND1), U1.F10 (GND2), U1.F11 (GND3), U1.G4 (GND4), U1.G5 (GND5), U1.G6 (GND6), U1.G7 (GND7), U1.G9 (GND8), U1.G10 (GND9), U1.G11 (GND10), U1.H3 (GND11), U1.H4 (GND12), U1.H5 (GND13), U1.H7 (GND14), U1.H9 (GND15), U1.H10 (GND16), U1.J3 (GND17), U1.J4 (GND18), U1.J6 (GND19), U1.J7 (GND58), U1.J9 (GND57), U1.J10 (GND56), U1.K3 (GND55), U1.K4 (GND54), U1.K6 (GND53), U1.K7 (GND52), U1.K10 (GND51), U1.K12 (GND50), U1.L4 (GND49), U1.L7 (GND48), U1.L9 (GND47), U1.L10 (GND46), U1.M10 (GND45), U1.N4 (GND43), U1.N8 (GND44), U1.R5 (GND42), U1.T1 (GND40), U1.T16 (GND41), U3.2 (GND), U4.4 (GND), U4.9 (GND), U5.2 (GND), U6.2 (GND), U7.10 (GND), U7.22 (VSYS), U7.25 (GND); also elsewhere on the board
I2C1_INT: U7.19 (ALERT); also elsewhere on the board
I2C1_SCL: U7.7 (SCL); also elsewhere on the board
I2C1_SDA: U7.8 (SDA); also elsewhere on the board
unnamed: C7.1, L1.1, U4.3 (SW)
unnamed: C7.2, U4.1 (BST)
unnamed: C17.1, U4.8 (SS)
unnamed: C18.1, R22.1
unnamed: C18.2, U4.6 (COMP)
unnamed: C38.2, D3.1 (K), J3.A4 (VBUS), J3.A9 (VBUS), J3.B4 (VBUS), J3.B9 (VBUS), Q1.1 (S), Q1.2 (S), Q1.3 (S), R26.2, R28.2, U7.24 (VDD)
unnamed: C39.2, R27.1
unnamed: C40.2, U7.21 (VREG_1V2)
unnamed: C41.2, U7.23 (VREG_2V7)
unnamed: D5.1 (K), J3.B5 (CC2), U7.4 (CC2), U7.5 (CC2DB)
unnamed: D5.2 (K), J3.A5 (CC1), U7.1 (CC1DB), U7.2 (CC1)
unnamed: J3.A6 (D+), J3.B6 (D+), R32.1
unnamed: J3.A7 (D-), J3.B7 (D-), R31.1
unnamed: L2.1, U3.3 (LX)
unnamed: L3.1, U5.3 (LX)
unnamed: Q1.4 (G), R26.1, R27.2, R29.2
unnamed: R16.2, R19.1, U3.5 (FB)
unnamed: R17.1, R20.2, U4.7 (EN)
unnamed: R18.2, R21.1, U4.5 (FB)
unnamed: R23.2, R24.1, U5.5 (FB)
unnamed: R25.1, U1.M6 (VDD_EFUSE)
unnamed: R28.1, U7.18 (VBUS_VS_DISCH)
unnamed: R29.1, U7.16 (VBUS_EN_SNK)
unnamed: R30.1, U7.9 (DISCH)
unnamed: R33.2, U7.13 (ADDR1)
unnamed: R34.2, U7.12 (ADDR0)
unnamed: R35.1, U7.6 (RESET)
USB-D_N: D6.1 (K), R31.2; also elsewhere on the board
USB-D_P: D6.2 (K), R32.2; also elsewhere on the board
VBUS: C39.1, C115.1, C116.1, D4.1 (K), Q1.5 (D), Q1.6 (D), Q1.7 (D), Q1.8 (D), R17.2, R30.2, U4.2 (VIN); also elsewhere on the board

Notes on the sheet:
ADR: 0x28

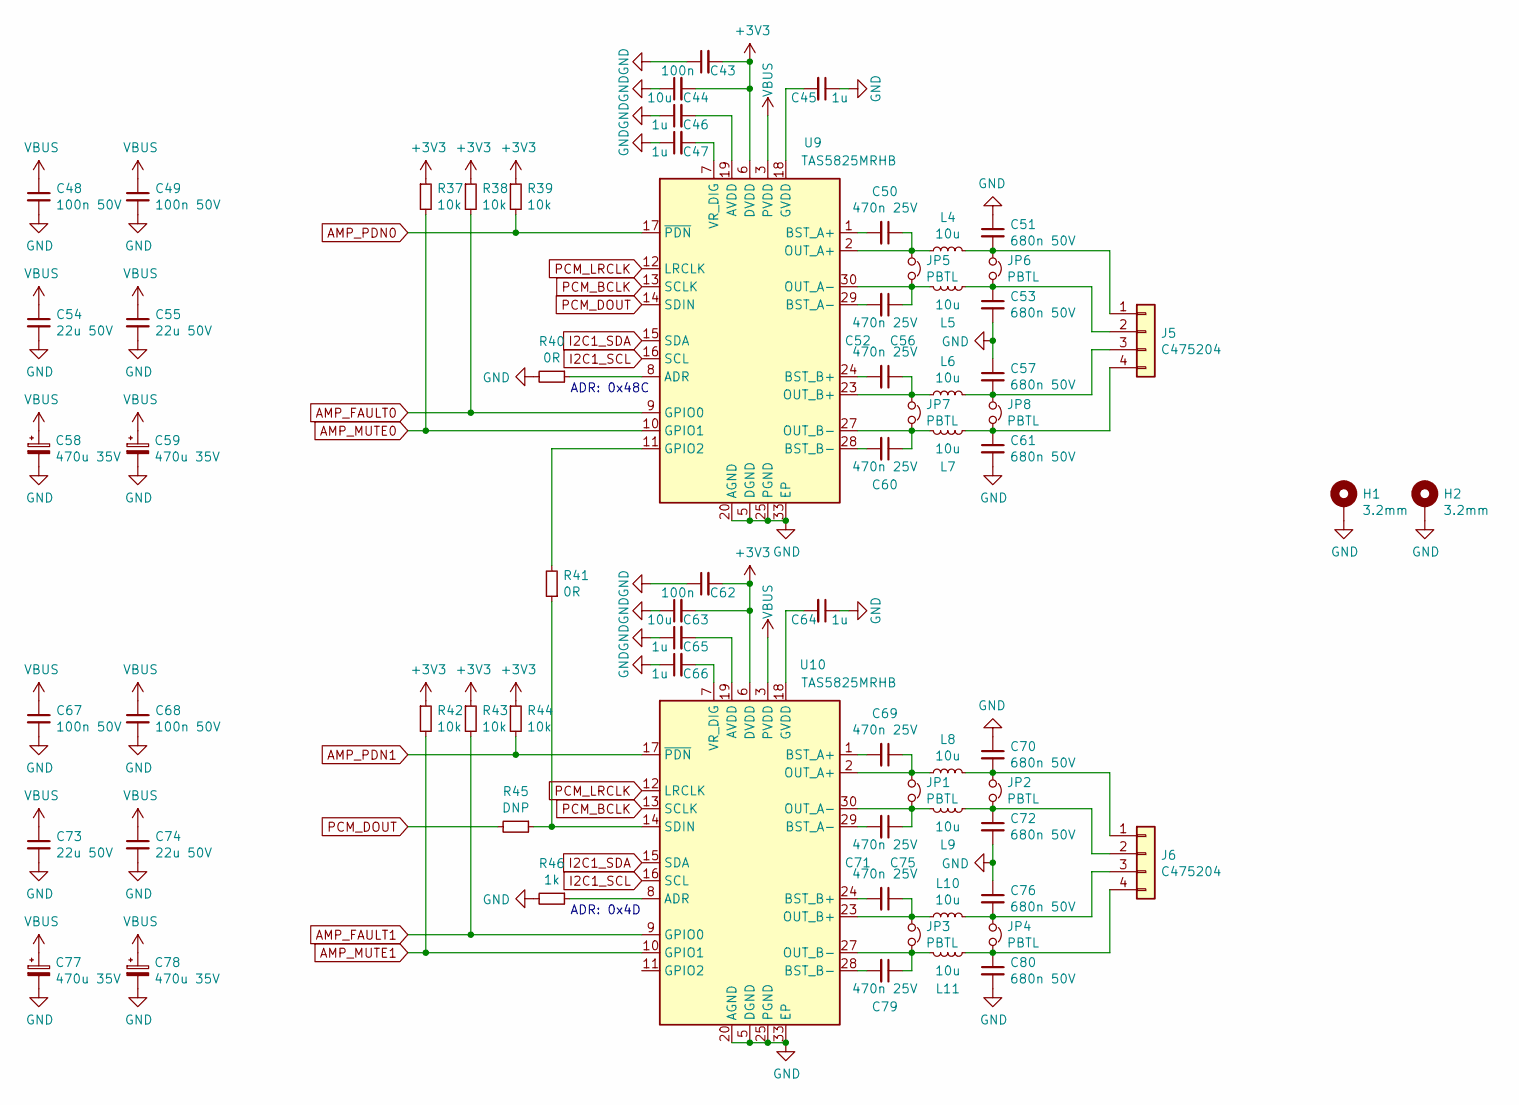
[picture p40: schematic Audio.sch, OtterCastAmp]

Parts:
C43, C62: 100n; C_0402
C44, C63: 10u; C_0603
C45, C46, C47, C64, C65, C66: 1u; C_0402
C48, C49, C67, C68: 100n 50V; C_0603
C50, C52, C56, C60, C69, C71, C75, C79: 470n 25V; C_0603
C51, C53, C57, C61, C70, C72, C76, C80: 680n 50V; C_1206_3216Metric
C54, C55, C73, C74: 22u 50V; C_1206_3216Metric
C58, C59, C77, C78: 470u 35V; CP_Elec_10x10.5
H1, H2: 3.2mm; MountingHole_3.2mm_M3_Pad_Via
J5, J6: C475204
JP1, JP2, JP3, JP4, JP5, JP6, JP7, JP8: PBTL; SolderJumper-2_P1.3mm_Open_Pad1.0x1.5mm
L4, L5, L6, L7, L8, L9, L10, L11: 10u; L_10.4x10.4_H4.8
R37, R38, R39, R42, R43, R44: 10k; R_0402
R40, R41: 0R; R_0402
R45: DNP; R_0402
R46: 1k; R_0402
U9, U10: TAS5825MRHB; Texas_S-PVQFN-N32_EP3.45x3.45mm

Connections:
AMP_FAULT0: R38.2, U9.9 (GPIO0); also elsewhere on the board
AMP_FAULT1: R43.2, U10.9 (GPIO0); also elsewhere on the board
AMP_MUTE0: R37.2, U9.10 (GPIO1); also elsewhere on the board
AMP_MUTE1: R42.2, U10.10 (GPIO1); also elsewhere on the board
AMP_PDN0: R39.2, U9.17 (~PDN); also elsewhere on the board
AMP_PDN1: R44.2, U10.17 (~PDN); also elsewhere on the board
GND: C43.1, C44.1, C45.1, C46.1, C47.1, C48.2, C49.2, C51.1, C53.2, C54.2, C55.2, C57.1, C58.2, C59.2, C61.2, C62.1, C63.1, C64.1, C65.1, C66.1, C67.2, C68.2, C70.1, C72.2, C73.2, C74.2, C76.1, C77.2, C78.2, C80.2, H1.1, H2.1, R40.2, R46.2, U9.5 (DGND), U9.20 (AGND), U9.25 (PGND), U9.26 (PGND), U9.31 (PGND), U9.32 (PGND), U9.33 (EP), U10.5 (DGND), U10.20 (AGND), U10.25 (PGND), U10.26 (PGND), U10.31 (PGND), U10.32 (PGND), U10.33 (EP); also elsewhere on the board
I2C1_SCL: U9.16 (SCL), U10.16 (SCL); also elsewhere on the board
I2C1_SDA: U9.15 (SDA), U10.15 (SDA); also elsewhere on the board
unnamed: C45.2, U9.18 (GVDD)
unnamed: C46.2, U9.19 (AVDD)
unnamed: C47.2, U9.7 (VR_DIG)
unnamed: C50.1, JP5.1, L4.1, U9.2 (OUT_A+)
unnamed: C50.2, U9.1 (BST_A+)
unnamed: C51.2, J5.1, JP6.1, L4.2
unnamed: C52.1, JP5.2, L5.2, U9.30 (OUT_A-)
unnamed: C52.2, U9.29 (BST_A-)
unnamed: C53.1, J5.2, JP6.2, L5.1
unnamed: C56.1, JP7.1, L6.1, U9.23 (OUT_B+)
unnamed: C56.2, U9.24 (BST_B+)
unnamed: C57.2, J5.3, JP8.1, L6.2
unnamed: C60.1, JP7.2, L7.2, U9.27 (OUT_B-)
unnamed: C60.2, U9.28 (BST_B-)
unnamed: C61.1, J5.4, JP8.2, L7.1
unnamed: C64.2, U10.18 (GVDD)
unnamed: C65.2, U10.19 (AVDD)
unnamed: C66.2, U10.7 (VR_DIG)
unnamed: C69.1, JP1.1, L8.1, U10.2 (OUT_A+)
unnamed: C69.2, U10.1 (BST_A+)
unnamed: C70.2, J6.1, JP2.1, L8.2
unnamed: C71.1, JP1.2, L9.2, U10.30 (OUT_A-)
unnamed: C71.2, U10.29 (BST_A-)
unnamed: C72.1, J6.2, JP2.2, L9.1
unnamed: C75.1, JP3.1, L10.1, U10.23 (OUT_B+)
unnamed: C75.2, U10.24 (BST_B+)
unnamed: C76.2, J6.3, JP4.1, L10.2
unnamed: C79.1, JP3.2, L11.2, U10.27 (OUT_B-)
unnamed: C79.2, U10.28 (BST_B-)
unnamed: C80.1, J6.4, JP4.2, L11.1
unnamed: R40.1, U9.8 (ADR)
unnamed: R41.1, R45.1, U10.14 (SDIN)
unnamed: R41.2, U9.11 (GPIO2)
unnamed: R46.1, U10.8 (ADR)
PCM_BCLK: U9.13 (SCLK), U10.13 (SCLK); also elsewhere on the board
PCM_DOUT: R45.2, U9.14 (SDIN); also elsewhere on the board
PCM_LRCLK: U9.12 (LRCLK), U10.12 (LRCLK); also elsewhere on the board
VBUS: C48.1, C49.1, C54.1, C55.1, C58.1, C59.1, C67.1, C68.1, C73.1, C74.1, C77.1, C78.1, U9.3 (PVDD), U9.4 (PVDD), U9.21 (PVDD), U9.22 (PVDD), U10.3 (PVDD), U10.4 (PVDD), U10.21 (PVDD), U10.22 (PVDD); also elsewhere on the board

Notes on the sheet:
ADR: 0x48C
ADR: 0x4D

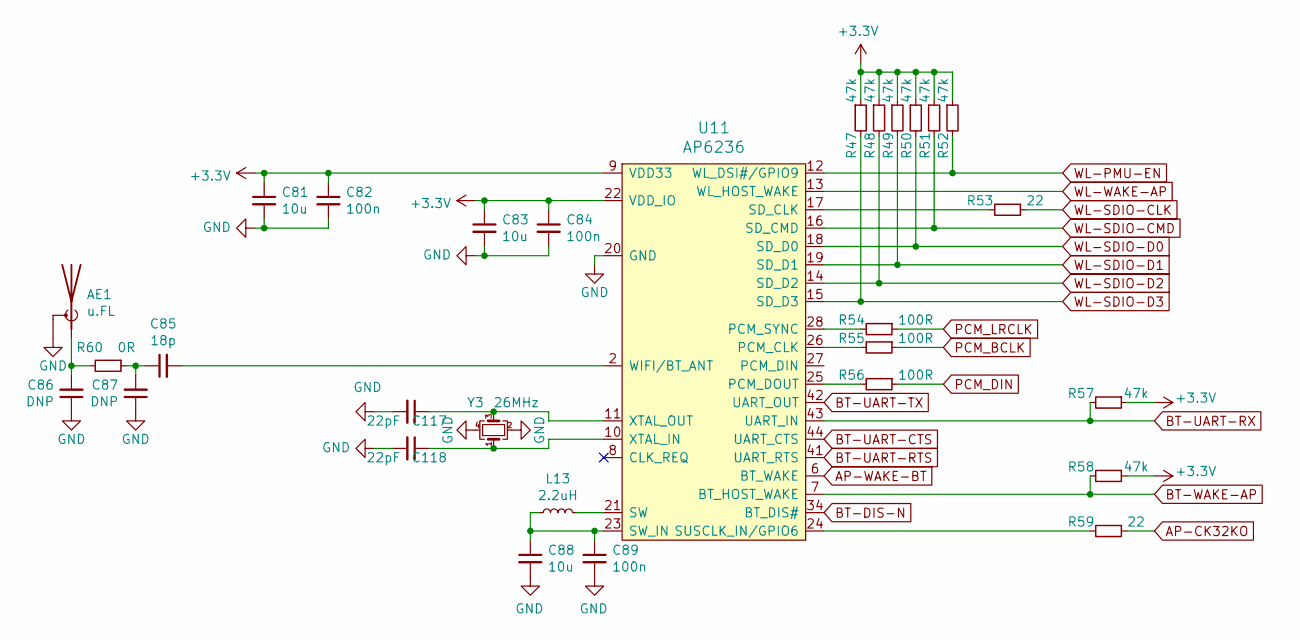
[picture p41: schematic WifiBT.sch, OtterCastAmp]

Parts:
AE1: u.FL; U.FL_Molex_MCRF_73412-0110_Vertical
C81, C83, C88: 10u; C_0603
C82, C84, C89: 100n; C_0402
C85: 18p; C_0402
C86, C87: DNP; C_0402
C117, C118: 22pF; C_0402
L13: 2.2uH; Inductor_4040; LCSC C167747
R47, R48, R49, R50, R51, R52, R57, R58: 47k; R_0402
R53, R59: 22; R_0402
R54, R55, R56: 100R; R_0402
R60: 0R; R_0402
U11: AP6236; LGA_44_12x12mm_0.9mm
Y3: 26MHz; Oscillator_3225

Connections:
AP-CK32KO: R59.1; also elsewhere on the board
AP-WAKE-BT: U11.6 (BT_WAKE); also elsewhere on the board
BT-DIS-N: U11.34 (BT_DIS#); also elsewhere on the board
BT-UART-CTS: U11.44 (UART_CTS); also elsewhere on the board
BT-UART-RTS: U11.41 (UART_RTS); also elsewhere on the board
BT-UART-RX: R57.2, U11.43 (UART_IN); also elsewhere on the board
BT-UART-TX: U11.42 (UART_OUT); also elsewhere on the board
BT-WAKE-AP: R58.2, U11.7 (BT_HOST_WAKE); also elsewhere on the board
GND: AE1.2 (Shield), C81.2, C82.2, C83.2, C84.2, C86.1, C87.1, C88.2, C89.2, C117.2, C118.2, U11.1 (GND), U11.20 (GND), U11.31 (GND), U11.33 (GND), U11.36 (GND), Y3.2, Y3.4; also elsewhere on the board
unnamed: AE1.1 (A), C86.2, R60.2
unnamed: C85.1, C87.2, R60.1
unnamed: C85.2, U11.2 (WIFI/BT_ANT)
unnamed: C88.1, C89.1, L13.1, U11.23 (SW_IN)
unnamed: C117.1, U11.11 (XTAL_OUT), Y3.3
unnamed: C118.1, U11.10 (XTAL_IN), Y3.1
unnamed: L13.2, U11.21 (SW)
unnamed: R53.2, U11.17 (SD_CLK)
unnamed: R54.2, U11.28 (PCM_SYNC)
unnamed: R55.2, U11.26 (PCM_CLK)
unnamed: R56.2, U11.25 (PCM_DOUT)
unnamed: R59.2, U11.24 (SUSCLK_IN/GPIO6)
PCM_BCLK: R55.1; also elsewhere on the board
PCM_DIN: R56.1; also elsewhere on the board
PCM_LRCLK: R54.1; also elsewhere on the board
WL-PMU-EN: R52.2, U11.12 (WL_DSI#/GPIO9); also elsewhere on the board
WL-SDIO-CLK: R53.1; also elsewhere on the board
WL-SDIO-CMD: R51.2, U11.16 (SD_CMD); also elsewhere on the board
WL-SDIO-D0: R50.2, U11.18 (SD_D0); also elsewhere on the board
WL-SDIO-D1: R49.2, U11.19 (SD_D1); also elsewhere on the board
WL-SDIO-D2: R48.2, U11.14 (SD_D2); also elsewhere on the board
WL-SDIO-D3: R47.2, U11.15 (SD_D3); also elsewhere on the board
WL-WAKE-AP: U11.13 (WL_HOST_WAKE); also elsewhere on the board

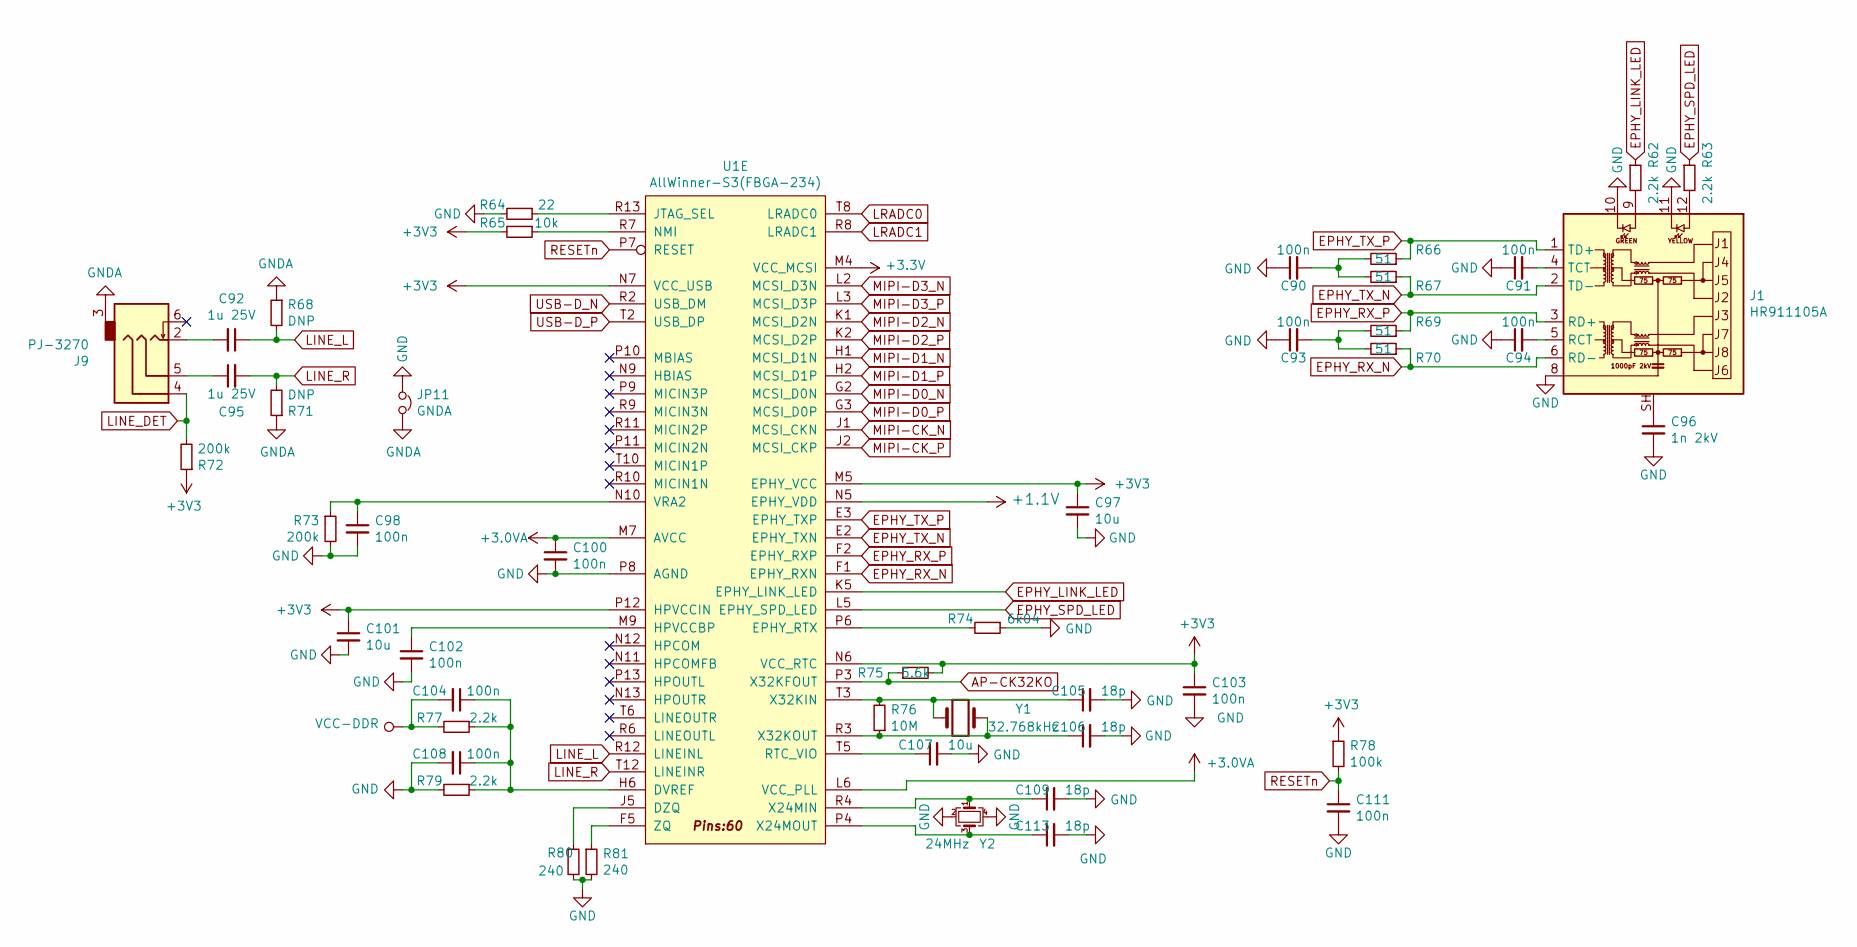
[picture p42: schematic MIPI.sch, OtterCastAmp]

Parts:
C90, C91, C93, C94, C98, C100, C102, C103, C104, C108, C111: 100n; C_0402
C92, C95: 1u 25V; C_0603
C96: 1n 2kV; C_1206_3216Metric
C97, C101, C107: 10u; C_0603
C105, C106, C109, C113: 18p; C_0402
J1: HR911105A; RJ45_Hanrun_HR911105A
J9: PJ-3270
JP11: GNDA; SolderJumper-2_P1.3mm_Bridged_Pad1.0x1.5mm
R62, R63, R77, R79: 2.2k; R_0402
R64: 22; R_0402
R65: 10k; R_0402
R66, R67, R69, R70: 51; R_0402
R68, R71: DNP; R_0402
R72, R73: 200k; R_0402
R74: 6k04; R_0402
R75: 5.6k; R_0402
R76: 10M; R_0402
R78: 100k; R_0402
R80, R81: 240; R_0402
U1: AllWinner-S3(FBGA-234); FBGA-234(Pitch-0.65mm_Pad-0.3mm_11x11x1.08mm)
Y1: 32.768kHz; Crystal_SMD_3215-2Pin_3.2x1.5mm
Y2: 24MHz; Oscillator_3225

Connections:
+1.1V: U1.N5 (EPHY_VDD); also elsewhere on the board
+1V5: C104.2, R77.2; also elsewhere on the board
+3.0VA: C100.1, U1.L6 (VCC_PLL), U1.M7 (AVCC); also elsewhere on the board
AP-CK32KO: R75.1, U1.P3 (X32KFOUT); also elsewhere on the board
EPHY_LINK_LED: R62.1, U1.K5 (EPHY_LINK_LED)
EPHY_RX_N: J1.6 (RD-), R70.1, U1.F1 (EPHY_RXN)
EPHY_RX_P: J1.3 (RD+), R69.1, U1.F2 (EPHY_RXP)
EPHY_SPD_LED: R63.1, U1.L5 (EPHY_SPD_LED)
EPHY_TX_N: J1.2 (TD-), R67.1, U1.E2 (EPHY_TXN)
EPHY_TX_P: J1.1 (TD+), R66.1, U1.E3 (EPHY_TXP)
GND: C90.1, C91.1, C93.1, C94.1, C96.2, C97.2, C98.2, C100.2, C101.2, C102.2, C103.2, C105.2, C106.2, C107.2, C108.2, C109.2, C111.2, C113.2, J1.8, J1.10, J1.11, JP11.1, R64.2, R73.2, R74.1, R79.2, R80.2, R81.2, U1.P8 (AGND), Y2.2, Y2.4; also elsewhere on the board
GNDA: J9.3, JP11.2, R68.1, R71.1
LINE_DET: J9.4, R72.2; also elsewhere on the board
LINE_L: C92.1, R68.2, U1.R12 (LINEINL)
LINE_R: C95.2, R71.2, U1.T12 (LINEINR)
LRADC0: U1.T8 (LRADC0)
LRADC1: U1.R8 (LRADC1)
MIPI-CK_N: U1.J1 (MCSI_CKN)
MIPI-CK_P: U1.J2 (MCSI_CKP)
MIPI-D0_N: U1.G2 (MCSI_D0N)
MIPI-D0_P: U1.G3 (MCSI_D0P)
MIPI-D1_N: U1.H1 (MCSI_D1N)
MIPI-D1_P: U1.H2 (MCSI_D1P)
MIPI-D2_N: U1.K1 (MCSI_D2N)
MIPI-D2_P: U1.K2 (MCSI_D2P)
MIPI-D3_N: U1.L2 (MCSI_D3N)
MIPI-D3_P: U1.L3 (MCSI_D3P)
unnamed: C90.2, R66.2, R67.2
unnamed: C91.2, J1.4 (TCT)
unnamed: C92.2, J9.2
unnamed: C93.2, R69.2, R70.2
unnamed: C94.2, J1.5 (RCT)
unnamed: C95.1, J9.5
unnamed: C96.1, J1.SH
unnamed: C98.1, R73.1, U1.N10 (VRA2)
unnamed: C102.1, U1.M9 (HPVCCBP)
unnamed: C104.1, C108.1, R77.1, R79.1, U1.H6 (DVREF)
unnamed: C105.1, R76.2, U1.T3 (X32KIN), Y1.1
unnamed: C106.1, R76.1, U1.R3 (X32KOUT), Y1.2
unnamed: C107.1, U1.T5 (RTC_VIO)
unnamed: C109.1, U1.R4 (X24MIN), Y2.1
unnamed: C113.1, U1.P4 (X24MOUT), Y2.3
unnamed: J1.9, R62.2
unnamed: J1.12, R63.2
unnamed: R64.1, U1.R13 (JTAG_SEL)
unnamed: R65.1, U1.R7 (NMI)
unnamed: R74.2, U1.P6 (EPHY_RTX)
unnamed: R80.1, U1.J5 (DZQ)
unnamed: R81.1, U1.F5 (ZQ)
RESETn: C111.1, R78.2, U1.P7 (RESET)
USB-D_N: U1.R2 (USB_DM); also elsewhere on the board
USB-D_P: U1.T2 (USB_DP); also elsewhere on the board

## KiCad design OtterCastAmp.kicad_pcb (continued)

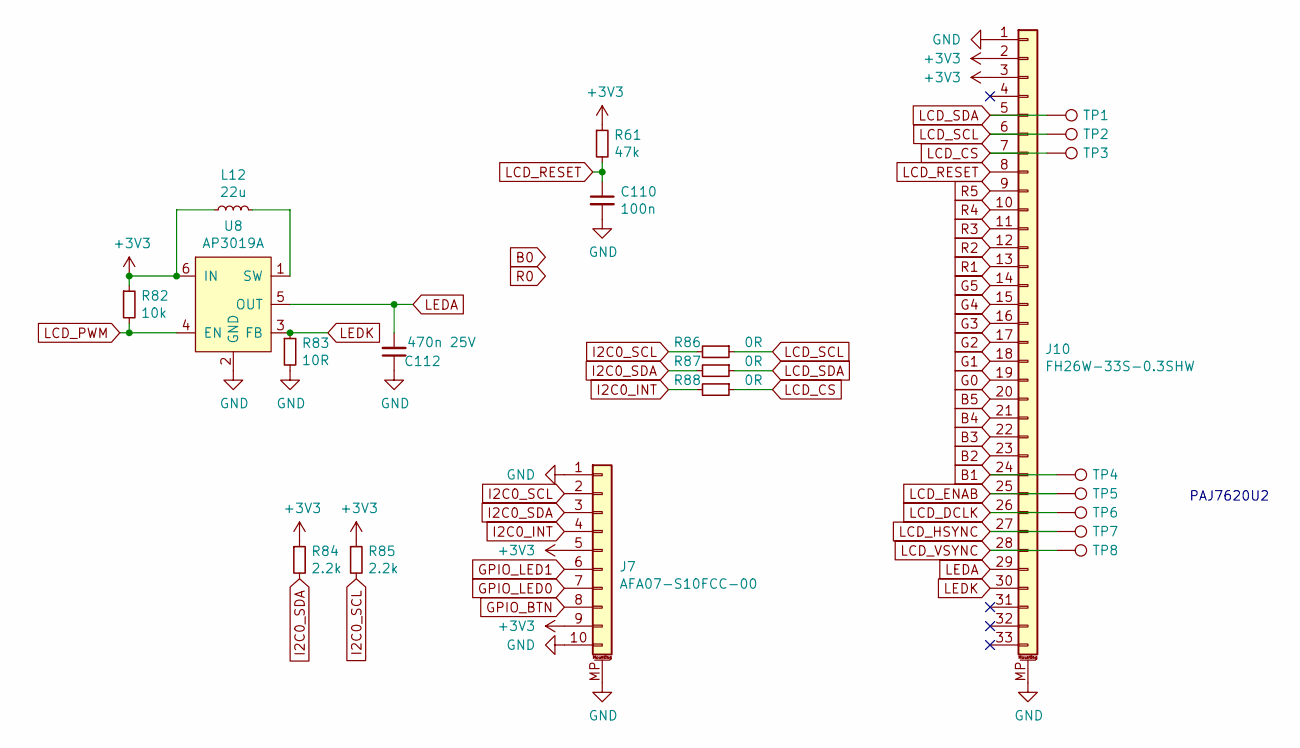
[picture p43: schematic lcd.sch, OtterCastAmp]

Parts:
C110: 100n; C_0402
C112: 470n 25V; C_0603
J7: AFA07-S10FCC-00; TE_1-84952-0_1x10-1MP_P1.0mm_Horizontal
J10: FH26W-33S-0.3SHW; Molex_502250-3391_2Rows-33Pins-1MP_P0.60mm_Horizontal
L12: 22u; Inductor_4040
R61: 47k; R_0402
R82: 10k; R_0402
R83: 10R; R_0402
R84, R85: 2.2k; R_0402
R86, R87, R88: 0R; R_0402
TP1, TP2, TP3, TP4, TP5, TP6, TP7, TP8: TestPoint; TestPoint_Pad_1.0x1.0mm
U8: AP3019A; SOT-23-6

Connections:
B1: J10.24, TP4.1; also elsewhere on the board
B2: J10.23; also elsewhere on the board
B3: J10.22; also elsewhere on the board
B4: J10.21; also elsewhere on the board
B5: J10.20; also elsewhere on the board
G0: J10.19; also elsewhere on the board
G1: J10.18; also elsewhere on the board
G2: J10.17; also elsewhere on the board
G3: J10.16; also elsewhere on the board
G4: J10.15; also elsewhere on the board
G5: J10.14; also elsewhere on the board
GND: C110.2, C112.1, J7.1, J7.10, J7.MP (MountPin), J10.1, J10.MP (MountPin), R83.2, U8.2 (GND); also elsewhere on the board
GPIO_BTN: J7.8; also elsewhere on the board
GPIO_LED0: J7.7; also elsewhere on the board
GPIO_LED1: J7.6; also elsewhere on the board
I2C0_INT: J7.4, R88.2; also elsewhere on the board
I2C0_SCL: J7.2, R85.2, R86.2; also elsewhere on the board
I2C0_SDA: J7.3, R84.2, R87.2; also elsewhere on the board
LCD_CS: J10.7, R88.1, TP3.1; also elsewhere on the board
LCD_DCLK: J10.26, TP6.1; also elsewhere on the board
LCD_ENAB: J10.25, TP5.1; also elsewhere on the board
LCD_HSYNC: J10.27, TP7.1; also elsewhere on the board
LCD_PWM: R82.2, U8.4 (EN); also elsewhere on the board
LCD_RESET: C110.1, J10.8, R61.2
LCD_SCL: J10.6, R86.1, TP2.1; also elsewhere on the board
LCD_SDA: J10.5, R87.1, TP1.1; also elsewhere on the board
LCD_VSYNC: J10.28, TP8.1; also elsewhere on the board
LEDA: C112.2, J10.29, U8.5 (OUT)
LEDK: J10.30, R83.1, U8.3 (FB)
unnamed: L12.2, U8.1 (SW)
R1: J10.13; also elsewhere on the board
R2: J10.12; also elsewhere on the board
R3: J10.11; also elsewhere on the board
R4: J10.10; also elsewhere on the board
R5: J10.9; also elsewhere on the board

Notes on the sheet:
PAJ7620U2

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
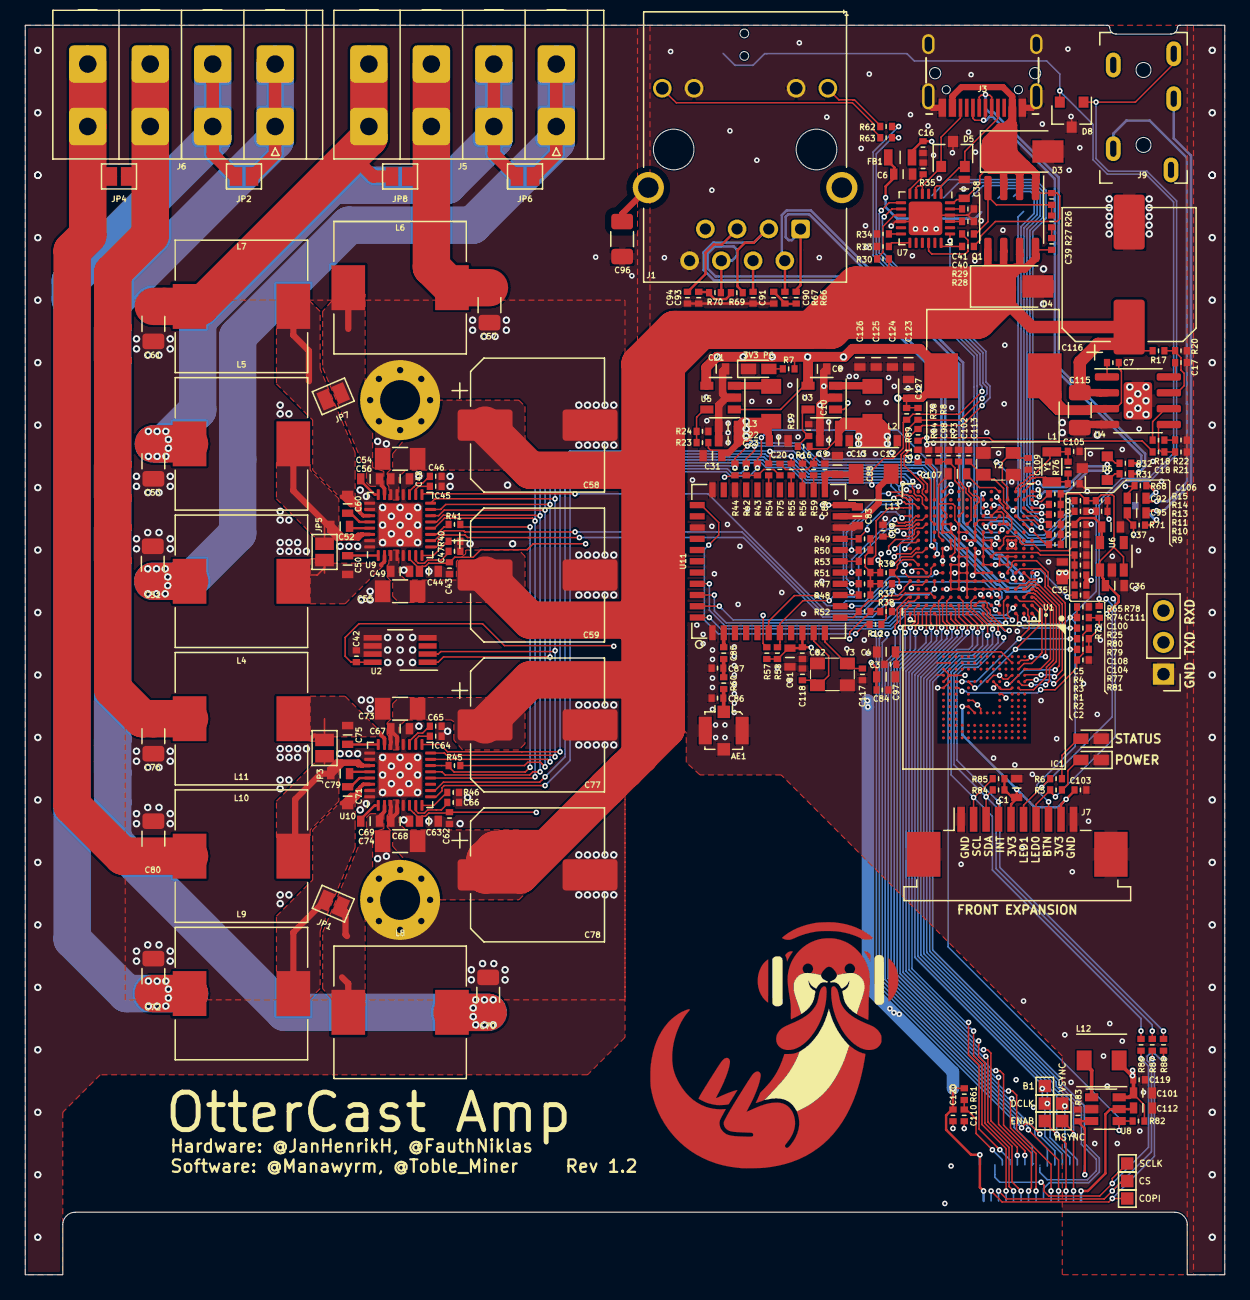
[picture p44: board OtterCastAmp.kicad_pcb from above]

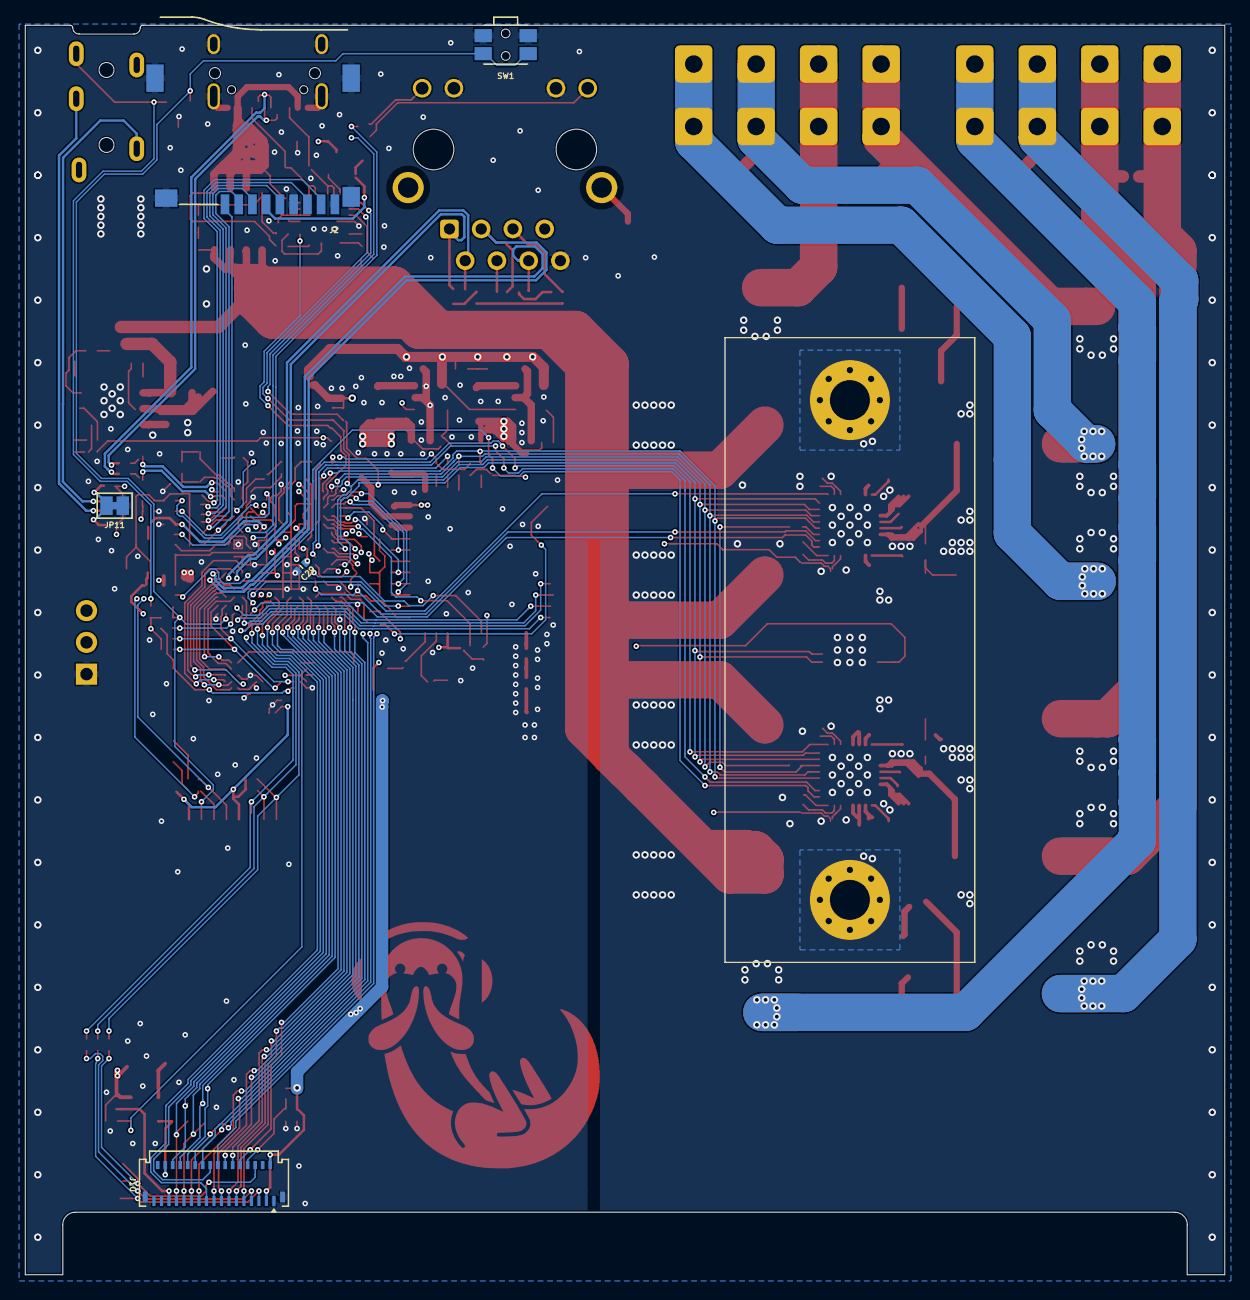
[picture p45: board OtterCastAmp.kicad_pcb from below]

Board: 4 copper layers, 96.0 x 100.0 mm, 269 parts (5 on the bottom side), 203 nets.

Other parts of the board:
3V3 PG: LED; LED_0603_1608Metric
B1: TestPoint; TestPoint_Pad_1.0x1.0mm
COPI: TestPoint; TestPoint_Pad_1.0x1.0mm
CS: TestPoint; TestPoint_Pad_1.0x1.0mm
DCLK: TestPoint; TestPoint_Pad_1.0x1.0mm
ENAB: TestPoint; TestPoint_Pad_1.0x1.0mm
HSYNC: TestPoint; TestPoint_Pad_1.0x1.0mm
SCLK: TestPoint; TestPoint_Pad_1.0x1.0mm
VSYNC: TestPoint; TestPoint_Pad_1.0x1.0mm

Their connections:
B1: B1.1; also elsewhere on the board
GND: 3V3 PG.1; also elsewhere on the board
LCD_CS: CS.1; also elsewhere on the board
LCD_DCLK: DCLK.1; also elsewhere on the board
LCD_ENAB: ENAB.1; also elsewhere on the board
LCD_HSYNC: HSYNC.1; also elsewhere on the board
LCD_SCL: SCLK.1; also elsewhere on the board
LCD_SDA: COPI.1; also elsewhere on the board
LCD_VSYNC: VSYNC.1; also elsewhere on the board
unnamed 141: 3V3 PG.2; also elsewhere on the board

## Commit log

2021-02-27 OtterCastAmp inital commit
    [Audio.sch, BOM.csv, BOM_v2.1.csv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]
2021-03-01 started layout
    [49F-1201GYD2NL.step, 9457710051.stp, ARJ-148.STEP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]
2021-03-01 layout final?
    [KF211R.stp, MIPI.sch, OtterCastAmp.kicad_pcb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]
2021-03-03 V1.0 order release
    [Audio.sch, KF211R.stp, MIPI.sch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]
2021-03-03 cleaned up libs
    [MIPI.sch, lcd.sch]
2021-04-12 V1.2 production release
    [Audio.sch, MIPI.sch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]
2021-04-19 removed step files
    [BGA-256_11.0x11.0mm_Layout20x20_P0.5mm_Ball0.3mm_Pad0.25mm_NSMD.step, HRO_TYPE-C-31-M-12.step, KF211R.stp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]
2021-04-19 readd 3D files
    [BGA-256_11.0x11.0mm_Layout20x20_P0.5mm_Ball0.3mm_Pad0.25mm_NSMD.step, HRO_TYPE-C-31-M-12.step, KF211R.stp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]

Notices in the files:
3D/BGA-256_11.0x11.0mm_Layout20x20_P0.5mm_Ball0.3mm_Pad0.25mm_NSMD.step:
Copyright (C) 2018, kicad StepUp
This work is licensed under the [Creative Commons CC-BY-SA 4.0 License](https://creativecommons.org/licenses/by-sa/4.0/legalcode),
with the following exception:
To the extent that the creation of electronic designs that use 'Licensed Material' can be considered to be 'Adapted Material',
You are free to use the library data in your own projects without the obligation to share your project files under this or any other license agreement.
